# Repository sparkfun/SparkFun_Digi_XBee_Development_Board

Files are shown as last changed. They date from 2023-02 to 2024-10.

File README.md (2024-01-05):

SparkFun Digi XBee® Development Board 
========================================

SparkFun Digi XBee® Development Board (https://www.sparkfun.com/products/21636)

[*SparkFun Digi XBee® Development Board  (21636)*](https://www.sparkfun.com/products/21636)

The SparkFun Digi XBee® Development Board is designed to help you quickly and easily prototype low-power cellular IoT applications using the new Digi XBee 3 Low-Power LTE-M/NB-IoT and Digi XBee RR Pro modules. This board breaks out all the functionality of your XBee module and adds the ability to connect to the cellular network and (drumroll, please) GNSS. 

This is a "kitchen sink" development board that gives you access to the pin functionality of the XBee, includes two USB-C connectors for UART communication and firmware updates, a Qwiic connector for I<sup>2</sup>C capable sensors and peripherals, as well as Reset and D0 buttons and the ability to update firmware on the XBees that have cellular modules. There's also a JST port for a battery to allow your project to be more on the go.

Repository Contents
-------------------

* **/Documentation** - Data sheets, additional product information
* **/Hardware** - Eagle design files (.brd, .sch)
* **/Production** - Production panel files (.brd)

Documentation
--------------
* **[Hookup Guide](https://docs.sparkfun.com/SparkFun_Digi_XBee_Development_Board/)** - Basic hookup guide for the SparkFun Digi XBee® Development Board.

License Information
-------------------

This product is _**open source**_! 

Please review the LICENSE.md file for license information. 

If you have any questions or concerns on licensing, please contact technical support on our [SparkFun forums](https://forum.sparkfun.com/viewforum.php?f=152).

Distributed as-is; no warranty is given.

- Your friends at SparkFun.

_<COLLABORATION CREDIT>_

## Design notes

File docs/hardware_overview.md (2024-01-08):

---
icon: material/cog
---

### Digi XBee® Smart Modem Socket

We've kept the Digi XBee socket consistent with the Digi XBee pinout, so this breakout board is backwards compatible. In order to take full advantage of this board, we recommend one of the newer Digi XBee boards. The [Digi XBee® 3 Low-Power LTE-M/NB-IoT, GNSS, no SIM](https://www.sparkfun.com/products/22329) is a great bet. 

<figure markdown>
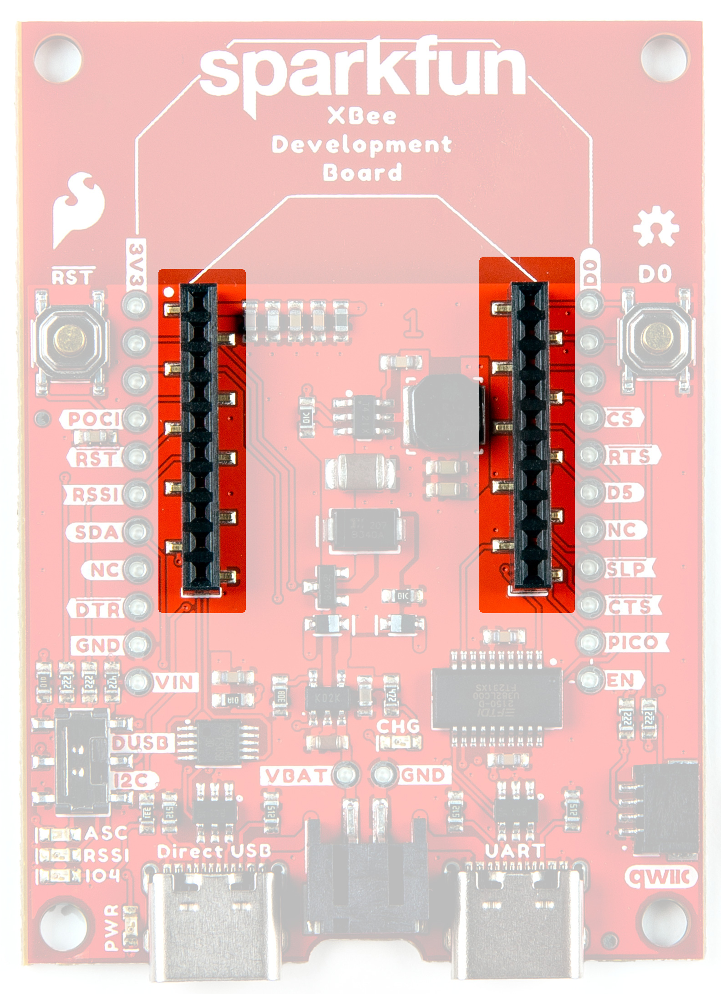
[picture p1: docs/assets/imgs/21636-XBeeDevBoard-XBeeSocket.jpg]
Digi XBee Socket

<figcaption markdown>Digi XBee Socket</figcaption>
</figure>

### Power and USB-C Connectors

There are two USB-C connectors on the board that can provide power. Both can be
plugged in simulatenously. Input VCC range is between <b>3.3V-5.5V</b>. 

<figure markdown>
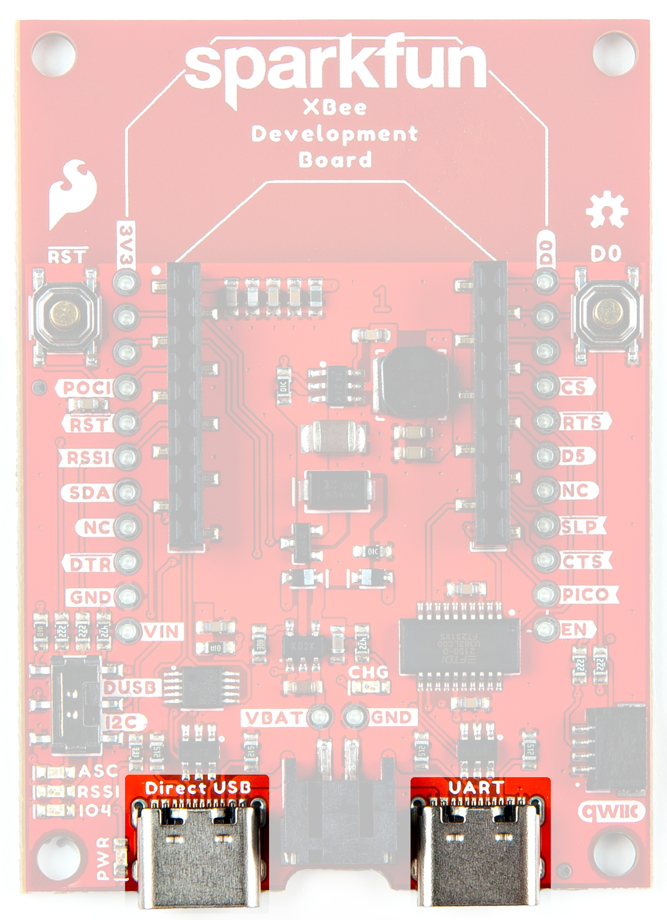
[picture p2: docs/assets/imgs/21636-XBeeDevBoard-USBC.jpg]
USB-C Connectors

<figcaption markdown>USB-C</figcaption>
</figure>

### Direct USB 

Digi XBee 3 modules with cellular capabilities have a u-blox cell module. The firmware for this module can be updated directly from the "Direct USB" USB-C connector. For more information, please refer to the [Digi XBee® 3 Cat1 Smart Modem User Guide](assets/BoardFiles/XBee3_LTE_Cat_1-UserGuide-90002503-1.pdf){ target="_blank" }. 

<figure markdown>
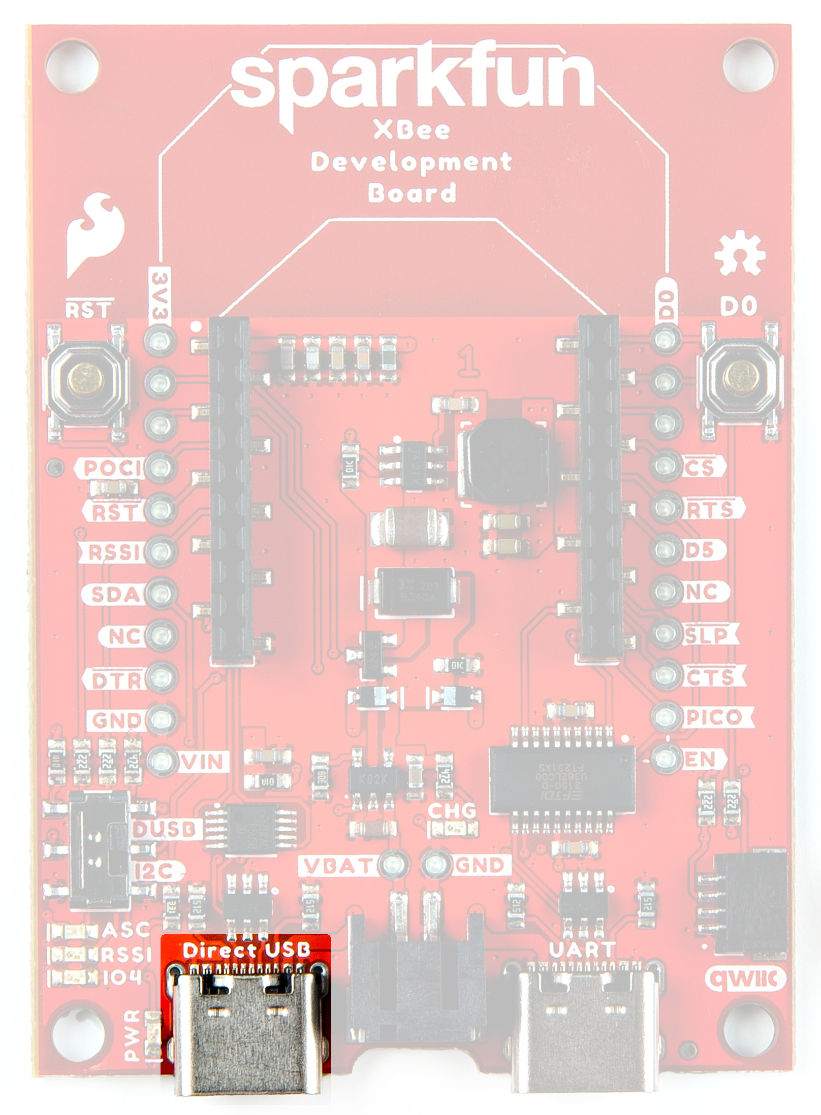
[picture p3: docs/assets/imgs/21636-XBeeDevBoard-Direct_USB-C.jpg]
Direct USB-C

<figcaption markdown>Direct USB-C</figcaption>
</figure>

### Qwiic Connector

The Qwiic connector on the SparkFun Digi XBee® Development Board provides power and I<sup>2</sup>C connectivity to Qwiic breakout boards. Note that I<sup>2</sup>C functionality is not enabled by default. 

<figure markdown>
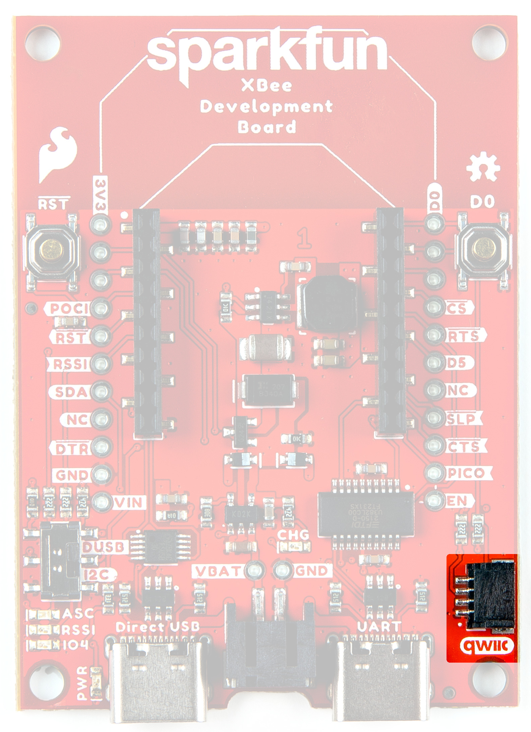
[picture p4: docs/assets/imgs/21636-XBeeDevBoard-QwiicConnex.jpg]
Qwiic Connector

<figcaption markdown>Qwiic Connector</figcaption>
</figure>

### USB Switch

The USB switch allows you to select between Direct USB and I<sup>2</sup>C. Default is Low (I<sup>2</sup>C/SDA).

<figure markdown>
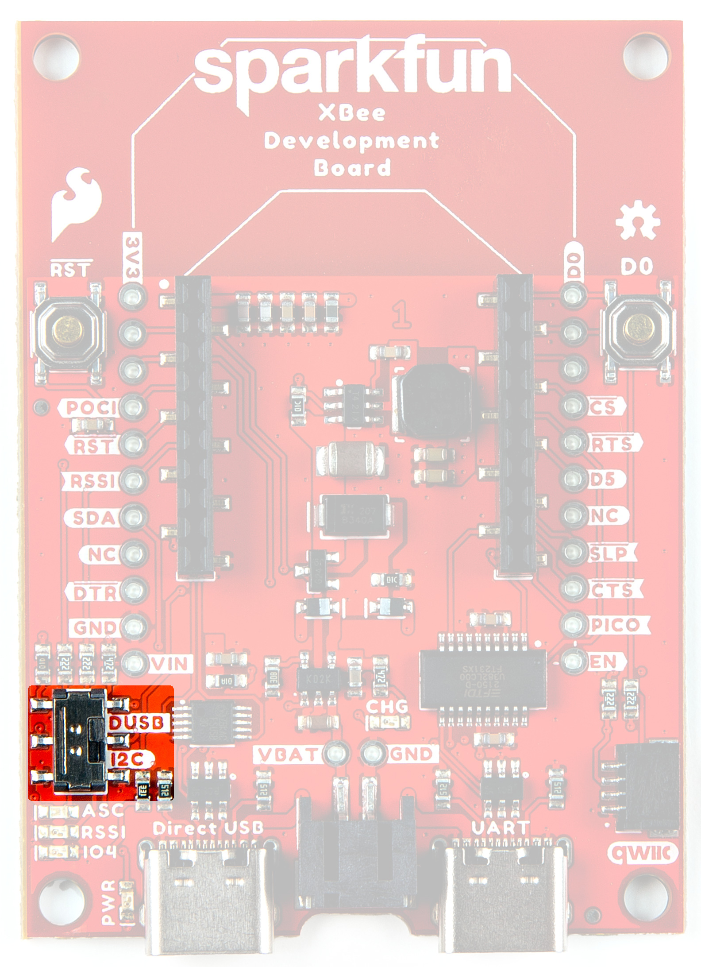
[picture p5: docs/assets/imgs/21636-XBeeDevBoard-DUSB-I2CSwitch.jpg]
DUSB I2C Switch

<figcaption markdown>DUSB I<sup>2</sup>C Switch</figcaption>
</figure>

### Buck Converter - AP63203

The AP63203 is a 2A, synchronous buck converter with a wide input voltage range that fully integrates a 125mΩ high-side power MOSFET and a 68mΩ lowside power MOSFET to provide high-efficiency step-down DC/DC conversion. VIN range is <b>3.8V-5.5V</b>. Output is 2A max. 

<figure markdown>
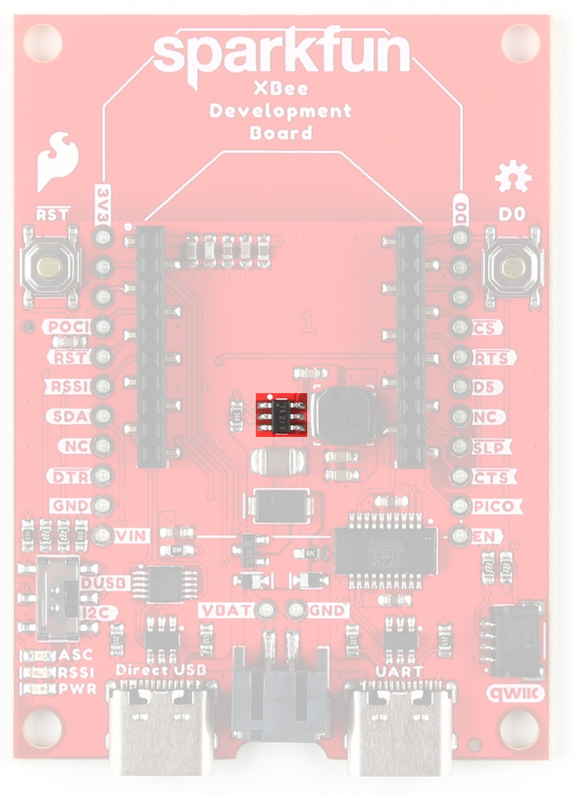
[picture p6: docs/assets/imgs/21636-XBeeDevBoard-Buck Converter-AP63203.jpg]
AP63203 Buck Converter

<figcaption markdown>AP63203 Buck Converter</figcaption>
</figure>

### USB to UART Bridge

The FT231XS translates data between your computer and the Digi XBee. This is one of our favorite chips because it supports all computer platforms and it's easy to work with. If this is the first FTDI chip you've ever connected to your computer (it probably won't be your last), there is some driver installation to get out of the way. We've written a tutorial detailing [How to Install FTDI Drivers tutorial](tutorials/74).

<figure markdown>
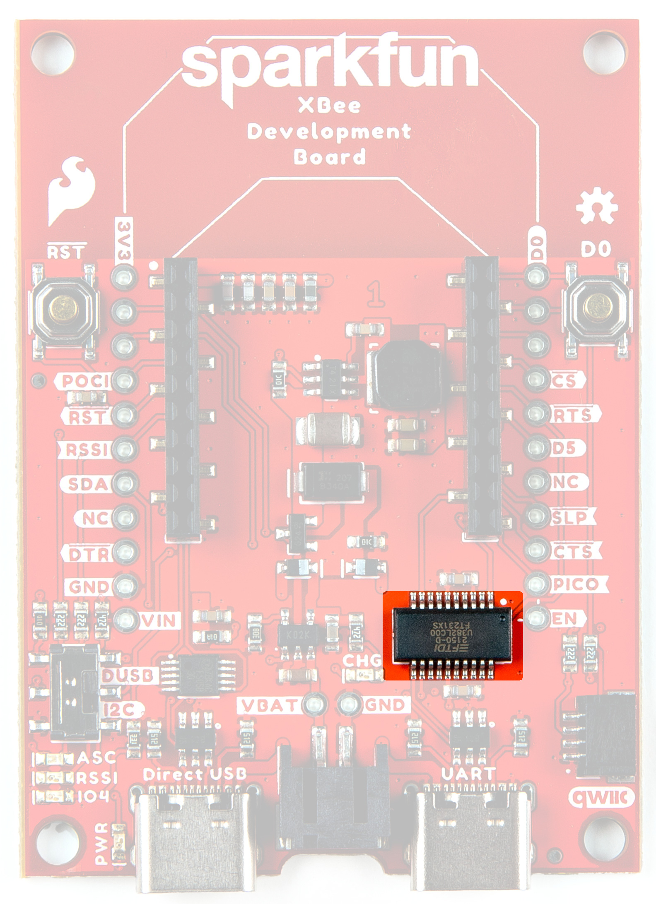
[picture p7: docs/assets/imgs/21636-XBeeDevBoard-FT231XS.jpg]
FT231XS USB to UART Bridge

<figcaption markdown>FT231XS USB to UART Bridge</figcaption>
</figure>

### Lipo Battery Connector

The SparkFun Digi XBee® Development Board includes support for single-cell lithium-polymer (LiPo) batteries, which plug into the board's black 2-pin JST connector. LiPos are perfect for projects on-the-go, or those that just need a little extra oomph. Bonus - you can charge your LiPo battery if the board is also plugged in. 

<figure markdown>
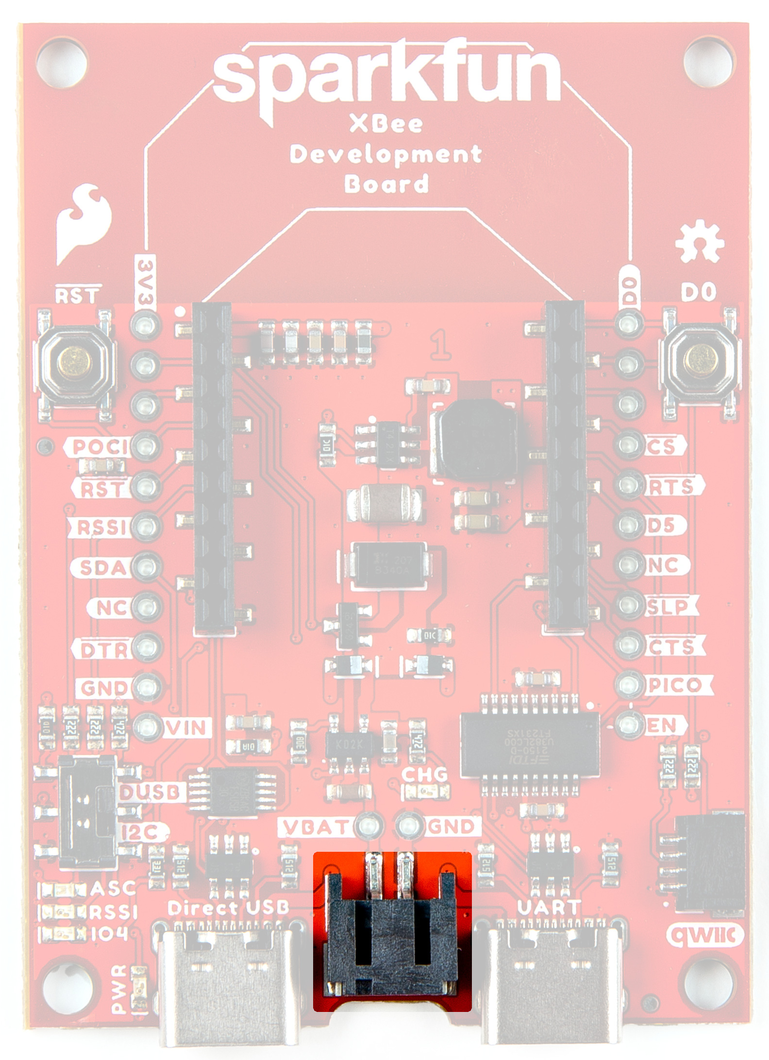
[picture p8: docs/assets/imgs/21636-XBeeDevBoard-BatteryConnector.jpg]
Battery Connector

<figcaption markdown>Battery Connector</figcaption>
</figure>

### GPIO

We've broken out the Digi XBee pins to plated through holes on either side of the board. 

<figure markdown>
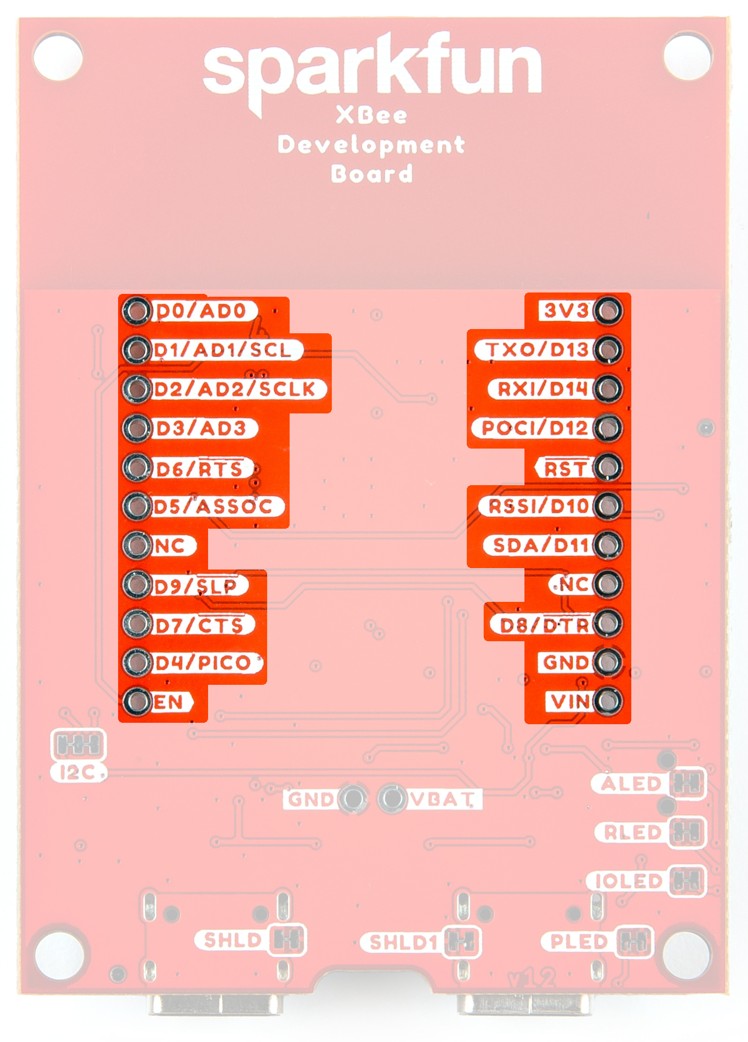
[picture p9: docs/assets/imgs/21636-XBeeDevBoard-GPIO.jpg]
GPIO

<figcaption markdown>GPIO</figcaption>
</figure>

### Buttons 

There are two buttons - D0 and RST. Reset allows you to reset the board without unplugging, the D0 button is provided for user-defined functionality. 

<figure markdown>
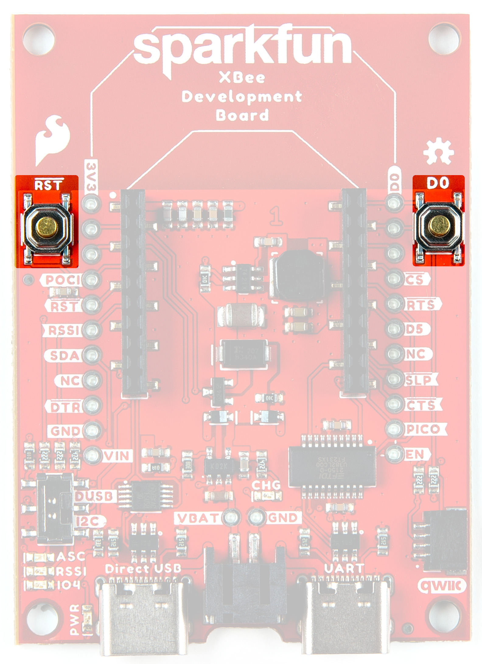
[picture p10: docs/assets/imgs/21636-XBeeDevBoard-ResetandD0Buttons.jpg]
Reset and D0 Buttons

<figcaption markdown>Reset and D0 Buttons</figcaption>
</figure>

### LEDs

There are multiple LED indicator lights on the board: 

<figure markdown>
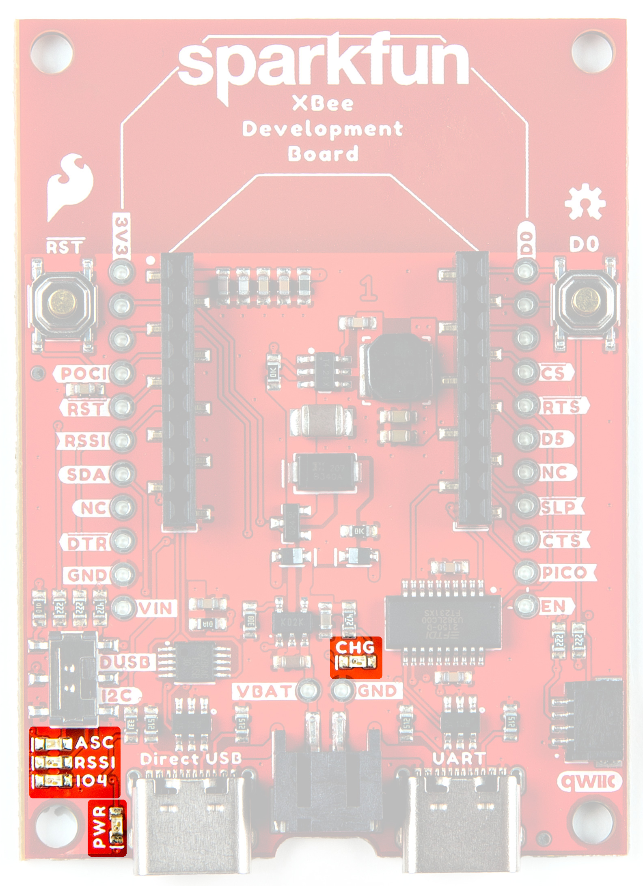
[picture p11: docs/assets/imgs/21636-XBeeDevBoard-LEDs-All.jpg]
LEDs

<figcaption markdown>LEDs</figcaption>
</figure>

#### CHG

This LED lights up when the charge circuit is in use.  

#### PWR

This LED lights up when power is provided to the board. 

#### IO4

This Green LED is a user-defined LED connected to D4 of the XBee. 

#### ASC
This LED on the development board blinks when the Digi XBee is registered to the cellular network.

| Blink | Timing | Meaning |
| --- | --- | --- |
| On | Solid | Not joined to a mobile network |
| Double Blink | ½ second | The last TCP/UDP/SMS attempt failed. If the LED has this pattern, you may need to check DI (Remote Manager Indicator) or CI (Protocol/Connection Indication) for the cause of the error. | 
| Single blink | 1 Second | Normal Operation |

#### RSSI 
This LED is the Received Signal Strength Indicator. When configured, it reflects the received signal strength.

RSSI PWM
The RSSI/PWM output is enabled continuously, unlike other Digi XBee products where the output is enabled for a short period of time after each received transmission. If running on the XBIB development board, DIO10 is connected to the RSSI LEDs, which may be interpreted as follows:

| PWM duty cycle | Number of LEDs turned on | Received signal strength (dBm) |
| --- | --- | --- |
| 79.39% or more | 3 | 83 dBm or higher |
| 62.42% to 79.39% | 2 | -93 to -83 dBm |
| 45.45% to 62.42% | 1 | -103 to -93 dBm |
| Less than 45.45% | 0 | Less than -103 dBm, or no cellular network connection |

### Jumpers

#### SHLD/SHLD1

For most applications, the single point grounding of the Direct USB or UART at the USB-C connector is sufficient. However, should you run into problems with EMI/EMC, we've provided jumpers that allow you to disconnect either connector from ground.

Cut the SHLD jumper for the UART USB-C; cut the SHLD1 jumper for Direct USB. 

<figure markdown>
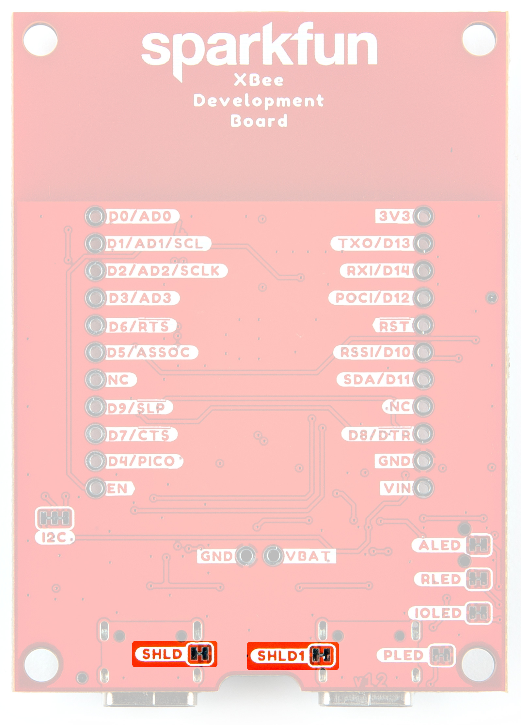
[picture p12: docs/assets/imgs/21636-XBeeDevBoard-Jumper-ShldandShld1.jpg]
Shield Jumpers

<figcaption markdown>Shield Jumpers</figcaption>
</figure>

#### ALED/PLED/RLED/IOLED

If power consumption is an issue (or if you just don't like the LEDs), cut the respective jumper to sever power to the LED. 

* PLED: Red
* ALED: Blue
* RLED (RSSI): Yellow
* IOLED: Green

<figure markdown>
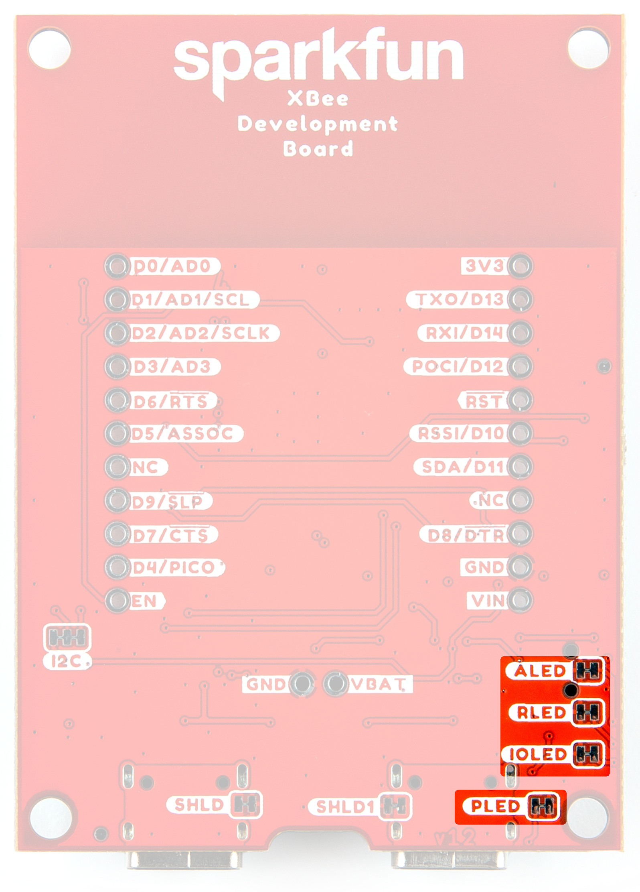
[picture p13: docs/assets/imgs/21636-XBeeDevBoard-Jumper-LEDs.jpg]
LED Jumpers

<figcaption markdown>LED Jumpers</figcaption>
</figure>

#### I2C 

The I<sup>2</sup>C jumper pulls the SDA and SCL pins to VDD (normally 3.3V) through two 2.2K Ohm resistors. If you have multiple Qwiic devices on the same bus you may want to disable these by opening the jumper (assuming they are also operating at 3.3V logic).

<figure markdown>
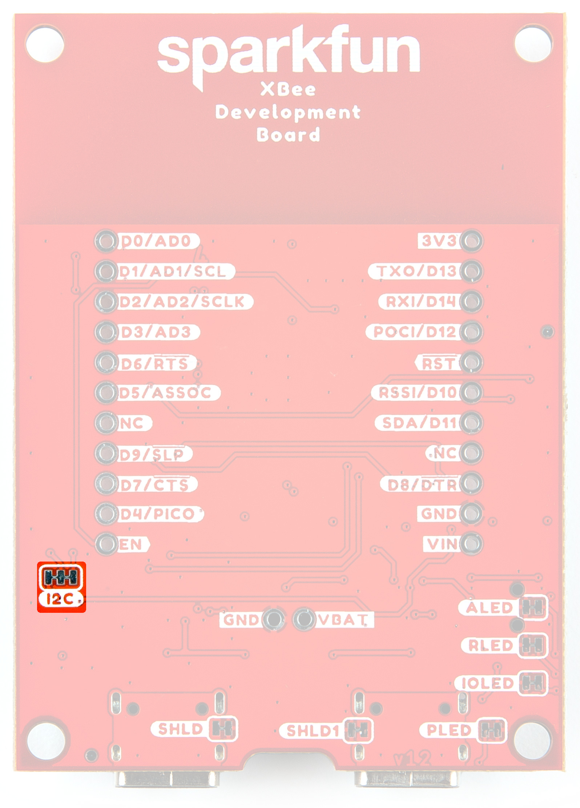
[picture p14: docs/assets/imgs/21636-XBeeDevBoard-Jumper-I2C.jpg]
I2C Jumper

<figcaption markdown>I<sup>2</sup>C Jumper</figcaption>
</figure>

### Board Outline

The overall size of the SparkFun Digi XBee® Development Board is 1.8" by 2.5". For specific measurements, see the image below. 

<figure markdown>
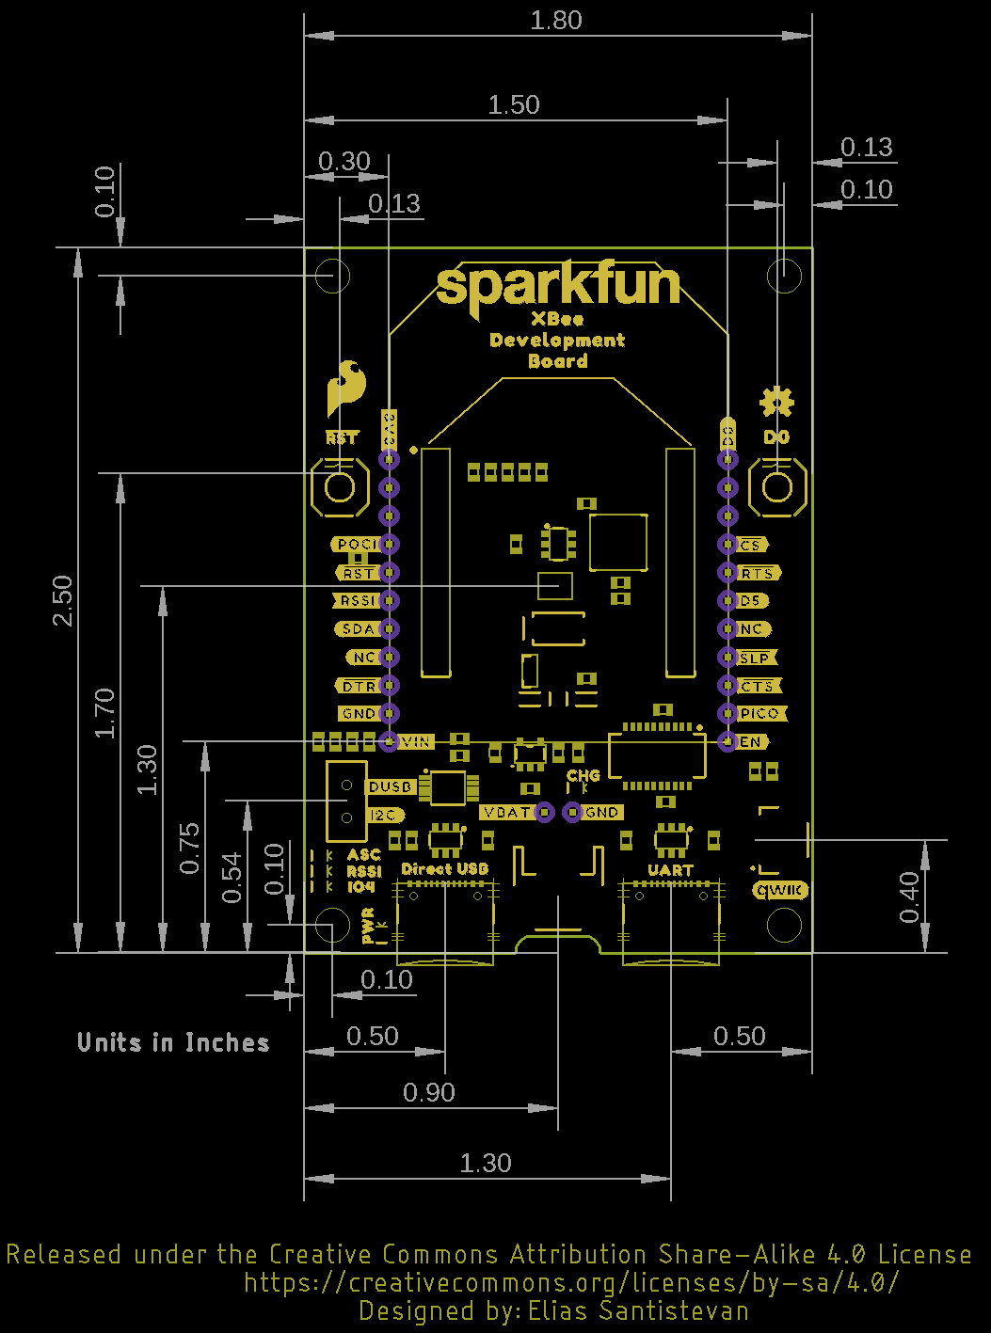
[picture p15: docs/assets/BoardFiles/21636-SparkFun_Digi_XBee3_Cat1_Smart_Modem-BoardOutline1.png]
Board Outline

<figcaption markdown>Board Outline</figcaption>
</figure>

??? tip "Need more measurements?"
	For more information about the board's dimensions, users can download the [Eagle files](assets/BoardFiles/SparkFun_Digi_XBee_Development_Board_EagleFiles.zip) for the board. These files can be opened in Eagle and additional measurements can be made with the dimensions tool.

	??? info ":octicons-download-16:{ .heart } Eagle - Free Download!"
		Eagle is a [CAD]("computer-aided design") program for electronics that is free to use for hobbyists and students. However, it does require an account registration to utilize the software.

		<center>
		[Download from<br>:autodesk-primary:{ .autodesk }](https://www.autodesk.com/products/eagle/free-download "Go to downloads page"){ .md-button .md-button--primary width="250px" }
		</center>
	
	??? info ":straight_ruler: Dimensions Tool"
		This video from Autodesk demonstrates how to utilize the dimensions tool in Eagle, to include additional measurements:

		<center>
		<div class="video">
		<iframe src="https://www.youtube.com/embed/dZLNd1FtNB8" title="EAGLE Dimension Tool" frameborder="0" allow="accelerometer; autoplay; clipboard-write; encrypted-media; gyroscope; picture-in-picture" allowfullscreen></iframe>
		</div>
		</center>

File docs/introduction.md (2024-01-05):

---
icon: material/book-open-page-variant
---

<div class="grid cards desc" markdown>

-    <a href="https://www.sparkfun.com/products/21636">
    **SparkFun Digi XBee® Development Board**<br>
    **SKU:** WRL-21636

    ---

    <figure markdown>
    Product Thumbnail
    </figure></a>
    
-    The SparkFun Digi XBee® Development Board is designed to help you quickly and easily prototype low-power cellular IoT applications using the new Digi XBee 3 Low-Power LTE-M/NB-IoT and Digi XBee RR Pro modules. This board breaks out all the functionality of your XBee module and adds the ability to connect to the cellular network and (drumroll, please) GNSS. This is a "kitchen sink" development board that gives you access to the pin functionality of the XBee, includes two USB-C connectors for UART communication and firmware updates, a Qwiic connector for I<sup>2</sup>C capable sensors and peripherals, as well as Reset and D0 buttons and the ability to update firmware on the XBees that have cellular modules. There's also a JST port for a battery to allow your project to be more on the go.

    <center>
    [Purchase from SparkFun :fontawesome-solid-cart-plus:{ .heart }](https://www.sparkfun.com/products/21636){ .md-button .md-button--primary }
    </center>

</div>

## Required Materials

To follow along with this tutorial, you will need the following materials. You may not need everything though depending on what you have. Add it to your cart, read through the guide, and adjust the cart as necessary.

<div class="grid cards" markdown>

-   <a href="https://www.sparkfun.com/products/21636">
    <figure markdown>
    Product Thumbnail
    </figure>

    ---

    **SparkFun Digi XBee® Development Board**<br>
    WRL-21636</a>

-   <a href="https://www.sparkfun.com/products/22329">
    <figure markdown>
    Product Thumbnail
    </figure>

    ---

    **Digi XBee® 3 Low-Power LTE-M/NB-IoT, GNSS, no SIM**<br>
    WRL-22329</a>

-   <a href="https://www.sparkfun.com/products/14743">
    <figure markdown>
    Product Thumbnail
    </figure>

    ---

    **USB 3.1 Cable A to C - 3 Foot**<br>
    CAB-14743</a>

</div>

## Suggested Reading

As a more professionally oriented product, we will skip over the more fundamental tutorials (i.e. [**Ohm's Law**](https://learn.sparkfun.com/tutorials/voltage-current-resistance-and-ohms-law) and [**What is Electricity?**](https://learn.sparkfun.com/tutorials/what-is-electricity)). However, below are a few tutorials that may help users familiarize themselves with various aspects of the board.

<div class="grid cards hide col-4" markdown align="center">

-   <a href="https://www.sparkfun.com/pages/xbee_guide">
    <figure markdown>
    XBee Buying Guide
    </figure>
    </a>
    <a href="https://www.sparkfun.com/pages/xbee_guide">**XBee Buying Guide**
    </a>

-   <a href="https://learn.sparkfun.com/tutorials/exploring-xbees-and-xctu">
    <figure markdown>
    Exploring XBees and XCTU
    </figure>
    </a>
    <a href="https://learn.sparkfun.com/tutorials/exploring-xbees-and-xctu">**Exploring XBees and XCTU**
    </a>    

-   <a href="https://learn.sparkfun.com/tutorials/serial-communication">
    <figure markdown>
    Serial Communication
    </figure>
    </a>
    <a href="https://learn.sparkfun.com/tutorials/serial-communication">**Serial Communication**
    </a>    

</div>

The SparkFun Digi XBee® Development Board takes advantage of the [Qwiic connect system](https://www.sparkfun.com/qwiic). We recommend familiarizing yourself with the **Logic Levels** and **I<sup>2</sup>C** tutorials. Click on the banner above to learn more about [Qwiic products](https://www.sparkfun.com/qwiic).

<center>
    <iframe width="600" height="327" src="https://www.youtube.com/embed/x0RDEHqFIF8" title="SparkFun's Qwiic Connect System" frameborder="0" allow="accelerometer; autoplay; clipboard-write; encrypted-media; gyroscope; picture-in-picture" allowfullscreen></iframe>
</center>

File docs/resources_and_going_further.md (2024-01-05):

For more information related to the SparkFun Digi XBee® Development Board, check out the resources below:

* [Schematic (PDF)](assets/BoardFiles/SparkFun_Digi_XBee_Development_Board_Schematic.pdf){ target="_blank" }
* [Eagle Files](assets/BoardFiles/SparkFun_Digi_XBee_Development_Board_EagleFiles.zip){ target="_blank" }
* [Board Outline (PNG)](assets/BoardFiles/21636-SparkFun_Digi_XBee3_Cat1_Smart_Modem-BoardOutline1.png){ target="_blank" }
* [GitHub Hardware Repo](https://github.com/sparkfun/SparkFun_Digi_XBee_Development_Board){ target="_blank" }
* [Digi XBee® 3 Cat1 Smart Modem User Guide](assets/BoardFiles/XBee3_LTE_Cat_1-UserGuide-90002503-1.pdf){ target="_blank" }

Or check out other [Digi XBee Projects](https://learn.sparkfun.com/tutorials/tags/xbee) for inspiration:

<table style="border-style:none">
    <tr>
        <td style="vertical-align: text-top;" width="264px">
            <a href="https://www.sparkfun.com/news/3252">
            
            <h3 style="vertical-align: left">Be All That You Can XBee
            </h3></a>
        </td>
        <td style="vertical-align: text-top;" width="264px">
            <div style="text-align: center"><a href="https://www.sparkfun.com/news/2891">
            </div>
            <h3 style="text-align: left">Wireless RC Robot with Arduino and XBees
            </h3></a>
        </td>
        <td style="vertical-align: text-top;" width="264px">
            <div style="text-align: center"><a href="https://www.sparkfun.com/news/2761">
            </div>
            <h3 style="text-align: left">Enginursday: Prototype Capacitive Touch Dance Floor with a Teensy and XBees
            </h3></a>
        </td>
        <td style="vertical-align: text-top;" width="264px">
            <a href="https://www.sparkfun.com/news/2911">
            
            <h3 style="text-align: left">Wireless Gesture-Controlled Robot
            </h3></a>
        </td>
    </tr>
</table>

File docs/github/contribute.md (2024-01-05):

# Contribute: Make an Augmentation!
Spot an improvement opportunity? Feel free to contribute to our open-source design and documentation. 

## :material-file-document-multiple:&nbsp;Improve our Documentation
All of this documentation can be modified by you! Please help us make it better.

* These pages are contained in the [`docs` folder](https://github.com/sparkfun/SparkFun_Digi_XBee_Development_Board/tree/main/docs) of the [SparkFun Digi XBee® Development Board repository](https://github.com/sparkfun/SparkFun_Digi_XBee_Development_Board).

<!-- ### :material-source-pull:&nbsp;Submit a Correction -->
### Submit a Correction

1. With a GitHub account, [fork this repository](https://github.com/sparkfun/SparkFun_Digi_XBee_Development_Board/fork).
2. Add your corrections or improvements to the markdown file.
3. File a pull request with your changes, and enjoy making the ~~words~~ ~~worlds~~ world a better place.
	* Once received, the documentation specialist will automatically be notified.
	* We will review your suggested improvements to make sure they are correct and fit within our documentation standards.

## :material-cog:&nbsp;Improve our Hardware Design
All of our designs are open-source! Please help us make it better.

* Our board design files are contained in the [`Hardware` folder](https://github.com/sparkfun/SparkFun_Digi_XBee_Development_Board/tree/main/Hardware) of the [SparkFun Digi XBee® Development Board repository](https://github.com/sparkfun/SparkFun_Digi_XBee_Development_Board).

<!-- ### :material-source-pull:&nbsp;Submit a Design Enhancement -->
### Submit a Design Enhancement

1. With a GitHub account, [fork this repository](https://github.com/sparkfun/SparkFun_Digi_XBee_Development_Board/fork).
2. Add your design augmentation(s)
3. File a pull request with your changes, and enjoy making the ~~words~~ ~~worlds~~ world a better place.
	1. Once received, the engineer in charge of the original design will automatically be notified.
	2. We will review your suggested improvement(s) to verify that they are within our board design standards and meet our product design requirements.
	3. If approved, we will flag these changes for our next board revision. Congrats! 🍻

		!!! info
			Even if your suggestion is accepted, these changes may not be immediately available for purchase. We may have to cycle through our current product inventory first.

## Contributors&nbsp;:clap:
Let's provide some recognition to the contributors for this project!

GitHub Contributors Image
<br>


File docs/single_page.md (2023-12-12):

---
hide:
  - navigation
  - toc
icon: fontawesome/solid/scroll
---

# Introduction
--8<-- "./docs/introduction.md:5"

# Hardware Overview
--8<-- "./docs/hardware_overview.md:5"

# Hardware Assembly
--8<-- "./docs/hardware_assembly.md:5"

## Software Setup
--8<-- "./docs/software_setup_and_programming.md:5"

# Troubleshooting Tips
--8<-- "./docs/troubleshooting.md:5"

# Resources:
--8<-- "./docs/resources_and_going_further.md:5"

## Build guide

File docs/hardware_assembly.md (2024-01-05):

---
icon: fontawesome/solid/screwdriver-wrench
---

Note the white silkscreen on the Shield PCB - this will help orient your Digi XBee as you're plugging it in. Make sure to match up the Digi XBee's two diagonal edges with the two diagonal lines on the PCB.

<figure markdown>
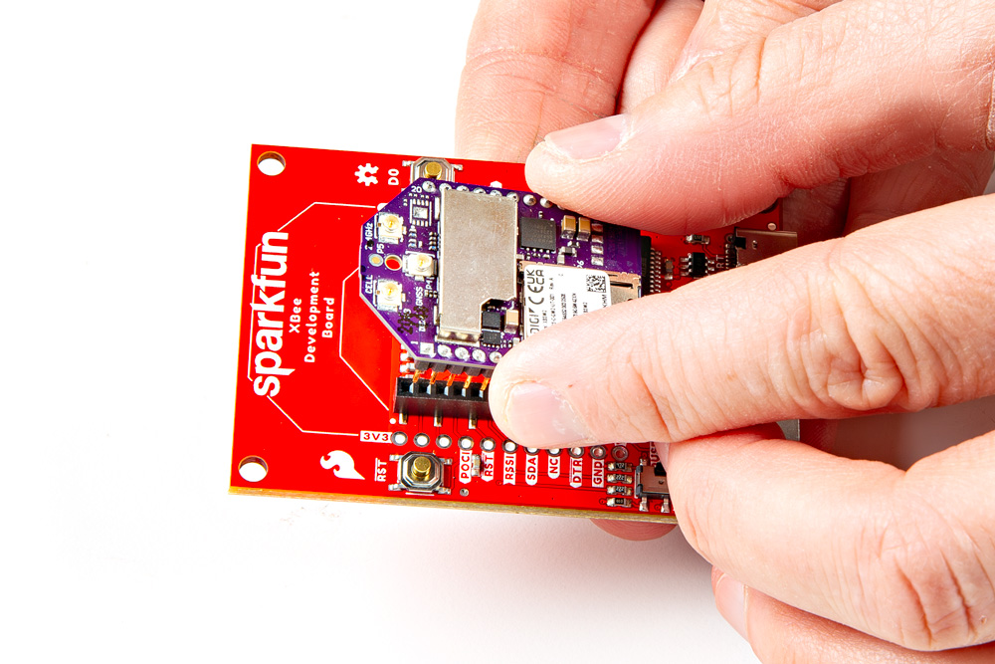
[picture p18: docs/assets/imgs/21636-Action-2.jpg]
Fitting the Digi XBee 3 into the Development Board's Socket

<figcaption markdown>Fitting the Digi XBee 3 into the SparkFun Digi XBee® Development Board's Socket</figcaption>
</figure>

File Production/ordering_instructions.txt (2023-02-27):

panel size, 106x216mm
PCB thickness, 1.6mm
number of layers, 4
soldermask color, Red
silkscreen color, White
oz copper, 1oz
finish, HASL lead free
stencils, top
pcs per panel, 6
min trace width, 0.2032mm / 0.0080in
min drill size, 0.3048mm / 0.0120in
filename to layer stackup 1/2/3/4: GTL, GL2, GL3, GBL

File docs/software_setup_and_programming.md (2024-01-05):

We have a number of tutorials detailing how to work with Digi XBees and their associated software. In particular, [XCTU](https://www.digi.com/products/embedded-systems/digi-xbee/digi-xbee-tools/xctu) is free software provided by Digi (the manufacturer of XBee), that provides a quick and easy way to configure and manage Digi XBees as well as test XBee networks. 

If you haven't worked with XCTU before, head on over to our [Exploring XBees and XCTU tutorial](https://learn.sparkfun.com/tutorials/exploring-xbees-and-xctu/all#starting-with-x-ctu) to get set up.  

<center><table class="tg">
  <tr>
    <th class="tg-v0mg"><a href="https://learn.sparkfun.com/tutorials/exploring-xbees-and-xctu/all#starting-with-x-ctu">Exploring XBees and XCTU tutorial</a></th>
  </tr>
  <tr>
    <td class="tg-v0mg"><i>Exploring XBees and XCTU tutorial</i></td>
  </tr>
</table>
</center>

You might also check out this [XBee WiFi Hookup Guide](https://learn.sparkfun.com/tutorials/xbee-wifi-hookup-guide) if your project includes WiFi! 

<center>
<table class="tg">
  <tr>
    <th class="tg-v0mg"><a href="https://learn.sparkfun.com/tutorials/xbee-wifi-hookup-guide">XBee WiFi Hookup Guide</a></th>
  </tr>
  <tr>
    <td class="tg-v0mg"><i>XBee WiFi Hookup Guide</i></td>
  </tr>
</table>
</center>

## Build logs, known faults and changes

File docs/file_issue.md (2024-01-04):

# Did we make a mistake?

Spot something wrong? Please let us know. 

!!! attention
    This is not where customers should seek assistance on a product. If you require technical assistance or have questions about a product that is not working as expected, please head over to the [SparkFun Technical Assistance](https://www.sparkfun.com/technical_assistance) page for some initial troubleshooting.
    <center>
    [SparkFun Technical Assistance Page](https://www.sparkfun.com/technical_assistance){ .md-button .md-button--primary }
    </center>
    
    If you can't find what you need there, you'll need a [Forum Account](https://forum.sparkfun.com/ucp.php?mode=register) to search product forums and post questions.

## Discrepancies in the Documentation

All of this documentation can be modified by you! Please help us make it better.

* The documentation files for these pages are contained in the [`docs` folder](https://github.com/sparkfun/SparkFun_XBee_Development_Board/tree/main/docs) of the [SparkFun Digi XBee® Development Board](https://github.com/sparkfun/SparkFun_XBee_Development_Board) repository.

### Spot something wrong?
If a section of the documentation is incorrect, please [open an issue](https://github.com/sparkfun/SparkFun_XBee_Development_Board/issues) and let us know.

### Do you have a suggested correction?
1. With a GitHub account, fork this repo
2. Add your correction(s) or improvement(s) to the markdown file(s)
3. File a pull request with your changes, and enjoy making the ~~words~~ ~~worlds~~ world a better place.
    * Once received, the documentation specialist will automatically be notified.
    * We will review your suggested improvement(s) to make sure they are correct and fit within our documentation standards.

## Problems in the Hardware Design

All of our designs are open-source! Please help us make it better.

* Our board design files are contained in the [`Hardware` folder](https://github.com/sparkfun/SparkFun_XBee_Development_Board/tree/main/Hardware) of the [SparkFun Digi XBee® Development Board](https://github.com/sparkfun/SparkFun_XBee_Development_Board) repository. 

### Does something not make sense?
If part of the design is confusing, please [open an issue](https://github.com/sparkfun/SparkFun_XBee_Development_Board/issues) and let us know.

### Did we forget to include an important function of the board?
* Please keep in mind that we may intentionally exclude certain functions of the board to meet our product design requirements. *(For example, our Qwiic Micro boards are intended to fit on a small board layout and only use I<sup>2</sup>C communication; therefore, we may not have the SPI and interrupt pins available for users.)*
* If part of the board's functionality is missing, please [open an issue](https://github.com/sparkfun/SparkFun_XBee_Development_Board/issues) and file a feature request.

### Do you wish to contribute directly to improving the board design?
1. With a GitHub account, Fork this repo
2. Add your design improvement(s)
3. File a pull request with your changes, and enjoy making the ~~words~~ ~~worlds~~ world a better place.
    * Once received, the engineer in charge of the original design will automatically be notified.
    * We will review your suggested improvement(s), if they are within our board design standards and meet our product design requirements, we will flag these changes for our next board revision. *(Please note, that even if your suggestion is accepted, these changes may not be immediate. We may have to cycle through our current product inventory first.)*

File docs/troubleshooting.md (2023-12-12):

---
icon: fontawesome/solid/question
---

!!! note
    <span class="glyphicon glyphicon-question-sign" aria-hidden="true"></span>
        <strong> Not working as expected and need help? </strong> <br /><br />

    If you need technical assistance and more information on a product that is not working as you expected, we recommend heading on over to the <a href="https://www.sparkfun.com/technical_assistance">SparkFun Technical Assistance</a> page for some initial troubleshooting. <br /><br />

    <div style="text-align: center"><a href="https://www.sparkfun.com/technical_assistance" target="sfe_technical_assistance" class="md-button">SparkFun Technical Assistance Page</a></div>

    If you don't find what you need there, the <a href="https://forum.sparkfun.com/index.php">SparkFun Forums</a> are a great place to find and ask for help. If this is your first visit, you'll need to <a href="https://forum.sparkfun.com/ucp.php?mode=register">create a Forum Account</a> to search product forums and post questions.<br /><br />

    <div style="text-align: center"><a href="https://forum.sparkfun.com/ucp.php?mode=register" class="md-button">Create New Forum Account</a>&nbsp;&nbsp;&nbsp;<a href="https://forum.sparkfun.com/index.php" class="md-button md-button--primary">Log Into SparkFun Forums</a></div>

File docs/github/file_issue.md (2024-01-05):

# Did we make a mistake?

Spot something wrong? Please let us know. 

<!-- Technical Assistance Box -->
!!! warning "Need Help?"
    If you need technical assistance or more information on a product that is not working as you expected, we recommend heading on over to the [SparkFun Technical Assistance](https://www.sparkfun.com/technical_assistanc) page for some initial troubleshooting. This **Submit Issues** page is not where users should seek assistance.

    <center>
    [SparkFun Technical Assistance Page](https://www.sparkfun.com/technical_assistance){ .md-button .md-button--primary }
    </center>
    
    If you can't find what you need there, the [SparkFun Forums](https://forum.sparkfun.com/index.php) is a great place to search the product forums and ask questions.
    
    !!! info "Account Registration Required"
        For your first visit to our forum, you'll need to create a [Forum Account](https://forum.sparkfun.com/ucp.php?mode=register) to post questions.

## Discrepancies in the Documentation

All of our documentation can be modified by you! Please help us make it better.

* The documentation files for these pages are contained in the [`docs` folder](https://github.com/sparkfun/SparkFun_Digi_XBee_Development_Board/tree/main/docs) of the [SparkFun Digi XBee® Development Board repository](https://github.com/sparkfun/SparkFun_Digi_XBee_Development_Board).

### 🔍 Spot something wrong?

If a section of the documentation is incorrect, please [open an issue](https://github.com/sparkfun/SparkFun_Digi_XBee_Development_Board/issues) and let us know.

### Do you have a suggested correction?

1. With a GitHub account, [fork this repository](https://github.com/sparkfun/SparkFun_Digi_XBee_Development_Board/fork).
2. Add your correction(s) or improvement(s) to the markdown file(s)
3. File a pull request with your changes, and enjoy making the ~~words~~ ~~worlds~~ world a better place.
	* Once received, the documentation specialist will automatically be notified.
	* We will review your suggested improvement(s) to make sure they are correct and fit within our documentation standards.

## Problems in the Hardware Design

All of our designs are open-source! Please help us make it better.

* Our board design files are contained in the [`Hardware` folder](https://github.com/sparkfun/SparkFun_Digi_XBee_Development_Board/tree/main/Hardware) of the [SparkFun Digi XBee® Development Board repository](https://github.com/sparkfun/SparkFun_Digi_XBee_Development_Board).

### Does something not make sense? 🤔

If part of the design is confusing, please [open an issue](https://github.com/sparkfun/SparkFun_Digi_XBee_Development_Board/issues) and let us know.

### Did we forget to include an important function of the board? 🤦

If part of the board's functionality is missing, please [open an issue](https://github.com/sparkfun/SparkFun_Digi_XBee_Development_Board/issues) and file a feature request.

!!! tip "Design Considerations"
	Please keep in mind that we may intentionally exclude certain functions of the board to meet our product design requirements.
	
	* *For example, our Qwiic Micro boards are intended to fit on a small board layout and only use I<sup>2</sup>C communication; therefore, we may not have the SPI and interrupt pins available for users.*

### Do you wish to contribute directly to improving the board design?

1. With a GitHub account, [fork this repository](https://github.com/sparkfun/SparkFun_Digi_XBee_Development_Board/fork).
2. Add your design augmentation(s)
3. File a pull request with your changes, and enjoy making the ~~words~~ ~~worlds~~ world a better place.
	1. Once received, the engineer in charge of the original design will automatically be notified.
	2. We will review your suggested improvement(s) to verify that they are within our board design standards and meet our product design requirements.
	3. If approved, we will flag these changes for our next board revision. Congrats! 🍻

		!!! info
			Even if your suggestion is accepted, these changes may not be immediately available for purchase. We may have to cycle through our current product inventory first.

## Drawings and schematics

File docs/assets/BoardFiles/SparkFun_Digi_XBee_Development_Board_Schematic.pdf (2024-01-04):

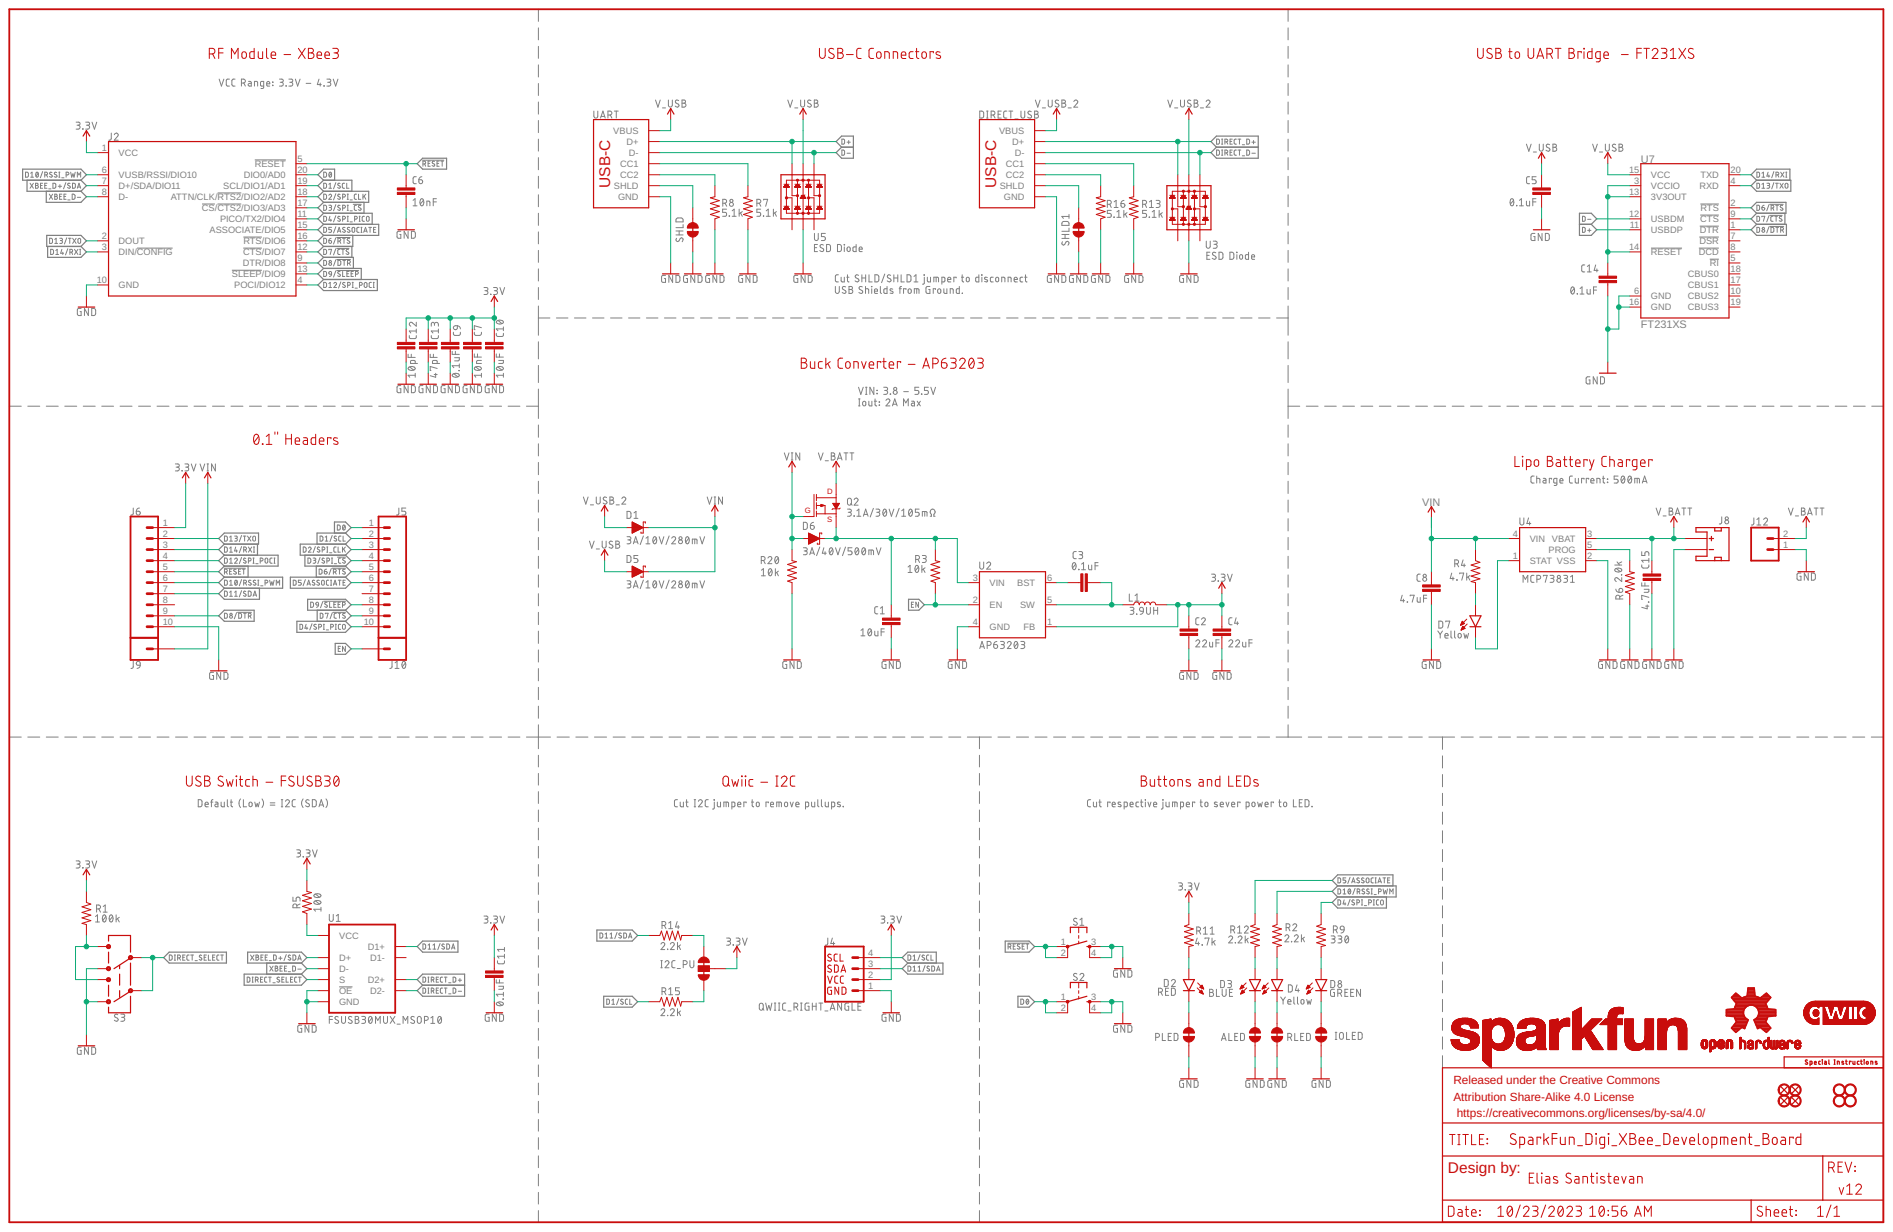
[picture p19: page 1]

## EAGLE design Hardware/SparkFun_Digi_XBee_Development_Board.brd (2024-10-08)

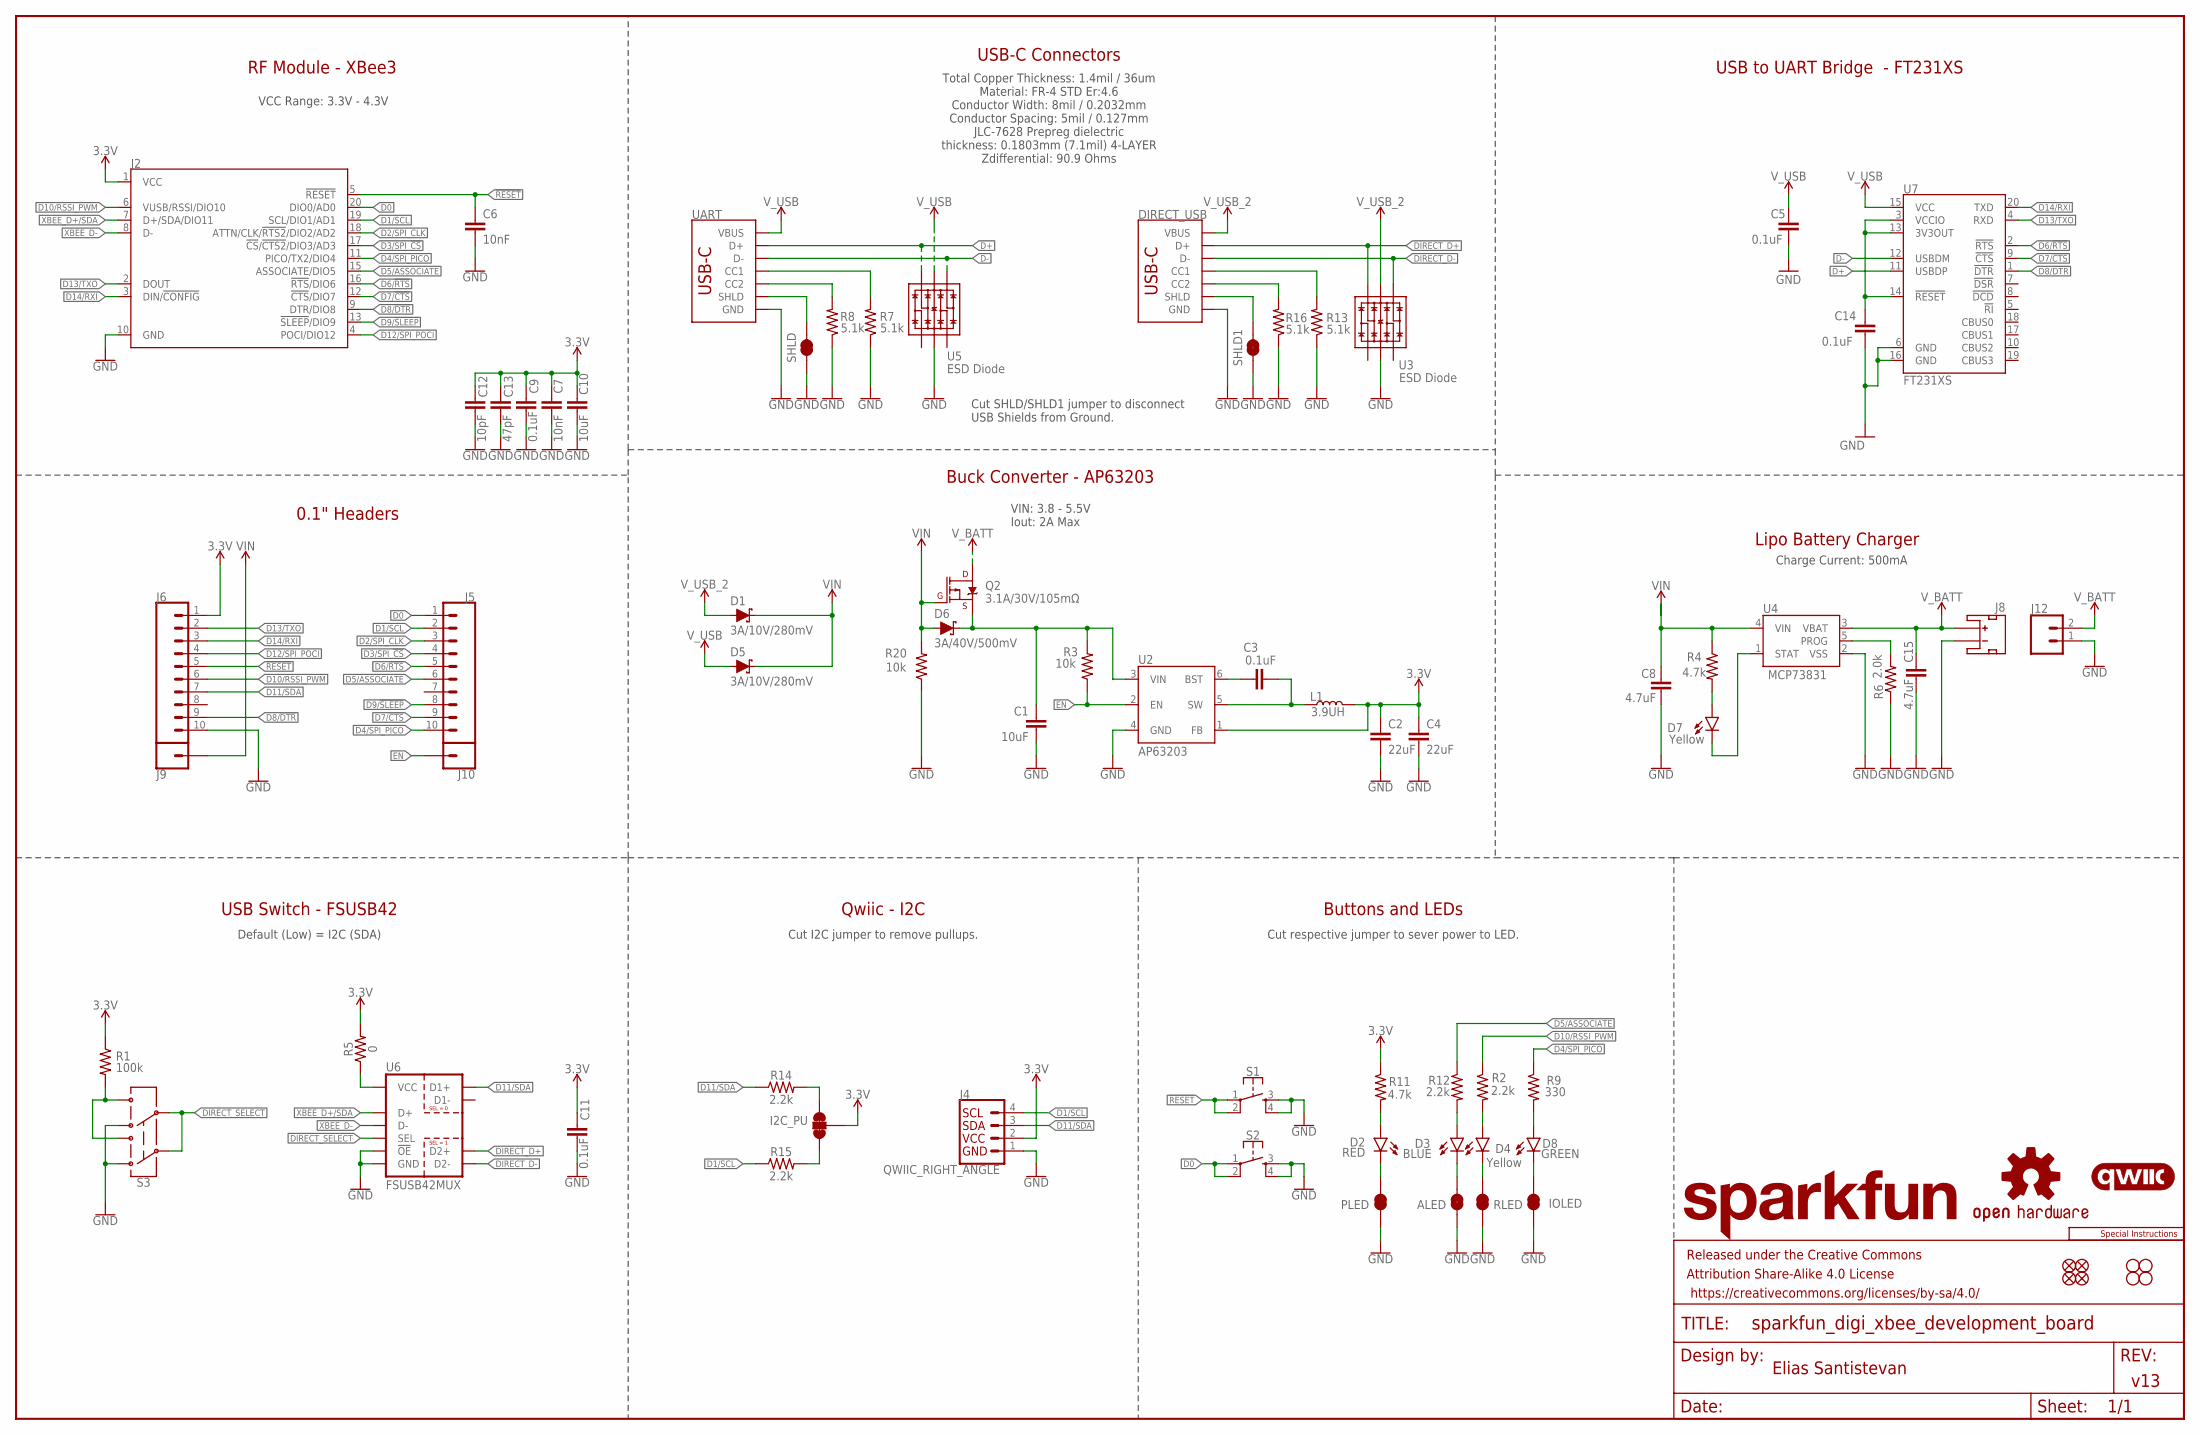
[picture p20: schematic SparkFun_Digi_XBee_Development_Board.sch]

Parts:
ALED: JUMPER-SMT_2_NC_TRACE_SILK; SMT-JUMPER_2_NC_TRACE_SILK
C1: 10uF; 1210
C2, C4: 22uF; 0603
C3, C5, C9, C11, C14: 0.1uF; 0603
C6, C7: 10nF; 0603
C8, C15: 4.7uF; 0603
C10: 10uF; 0603
C12: 10pF; 0603
C13: 47pF; 0603
D1, D5: 3A/10V/280mV; SOD-323
D2: RED; LED-0603
D3: BLUE; LED-0603
D4, D7: Yellow; LED-0603
D6: 3A/40V/500mV; SMA-DIODE
D8: GREEN; LED-0603
DIRECT_USB: USB Female Type C Connector; USB-C-16P-4LAYER-ISOLATED
FD1, FD2, FD3, FD4: FIDUCIAL1X2; FIDUCIAL-1X2
FRAME1: FRAME-LEDGER; CREATIVE_COMMONS
H1, H2, H3, H4: STAND-OFFTIGHT; STAND-OFF-TIGHT
I2C_PU: JUMPER-SMT_3_2-NC_TRACE_SILK; SMT-JUMPER_3_2-NC_TRACE_SILK
IOLED: JUMPER-SMT_2_NC_TRACE_SILK; SMT-JUMPER_2_NC_TRACE_SILK
J2: XBEE_UPDATEXBEE_SMD; XBEE3-SMD
J4: QWIIC_RIGHT_ANGLE; JST04_1MM_RA
J5, J6: CONN_10NO_SILK_PTH_FEMALE; 1X10_NO_SILK
J8: JST_2MM_MALE; JST-2-SMD
J9, J10: CONN_01PTH_NO_SILK_STAND; 1X01_NO_SILK_STAND
J12: CONN_021X02_NO_SILK; 1X02_NO_SILK
L1: 3.9UH; INDUCTOR_3.9UH
LOGO1: SFE_LOGO_NAME.2_INCH; SFE_LOGO_NAME_.2
LOGO2: OSHW-LOGOS; OSHW-LOGO-S
LOGO3: QWIIC_LOGO_5MM; QWIIC_5MM
LOGO5: SPECIAL_INSTRUCTIONS-ORDERING; ORDERING_INSTRUCTIONS
PLED: JUMPER-SMT_2_NC_TRACE_SILK; SMT-JUMPER_2_NC_TRACE_SILK
Q2: 3.1A/30V/105mΩ; SOT23-3
R1: 100k; 0603
R2, R12, R14, R15: 2.2k; 0603
R3, R20: 10k; 0603
R4, R11: 4.7k; 0603
R5: 0; 0603
R6: 2.0k; 0603
R7, R8, R13, R16: 5.1k; 0603
R9: 330; 0603
RLED: JUMPER-SMT_2_NC_TRACE_SILK; SMT-JUMPER_2_NC_TRACE_SILK
S1, S2: MOMENTARY-SWITCH-SPST-2-SMD-5.2MM-TALL; TACTILE_SWITCH_SMD_5.2MM
S3: SWITCH-DPDT-SMD-AYZ0202; SWITCH_DPDT_SMD_AYZ0202
SHLD, SHLD1: JUMPER-SMT_2_NC_TRACE_SILK; SMT-JUMPER_2_NC_TRACE_SILK
U2: AP63203; SOT23-6
U3, U5: ESD Diode; SOT-23-6
U4: MCP73831; SOT23-5
U6: FSUSB42MUX; MSOP10
U7: FT231XS; SSOP20_L
UART: USB Female Type C Connector; USB-C-16P-4LAYER-ISOLATED

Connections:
3.3V: C2.1, C4.1, C7.1, C9.1, C10.1, C11.1, C12.1, C13.1, I2C_PU.2, J2.1 (VCC), J4.2, J6.1, L1.P$2 (2), R1.1, R5.2, R11.1, U2.1 (FB)
!RESET!: C6.1, J2.5 (!RESET!), J6.5, S1.1, S1.2
ALED: ALED.2, D3.C
D0: J2.20 (DIO0/AD0), J5.1, S2.1, S2.2
D1/SCL: J2.19 (SCL/DIO1/AD1), J4.4, J5.2, R15.1
D2/SPI_CLK: J2.18 (ATTN/CLK/!RTS2!/DIO2/AD2), J5.3
D3/SPI_!CS!: J2.17 (!CS!/!CTS2!/DIO3/AD3), J5.4
D4/SPI_PICO: J2.11 (PICO/TX2/DIO4), J5.10, R9.1
D5/ASSOCIATE: J2.15 (ASSOCIATE/DIO5), J5.6, R12.1
D6/!RTS!: J2.16 (!RTS!/DIO6), J5.5, U7.2 (!RTS)
D7/!CTS!: J2.12 (!CTS!/DIO7), J5.9, U7.9 (!CTS)
D8/!DTR!: J2.9 (DTR/DIO8), J6.9, U7.1 (!DTR)
D9/!SLEEP!: J2.13 (!SLEEP!/DIO9), J5.8
D10/RSSI_PWM: J2.6 (VUSB/RSSI/DIO10), J6.6, R2.1
D11/SDA: J4.3, J6.7, R14.1, U6.7 (D1+)
D12/SPI_POCI: J2.4 (POCI/DIO12), J6.4
D13/TXO: J2.2 (DOUT), J6.2, U7.4 (RXD)
D14/RXI: J2.3 (DIN/!CONFIG!), J6.3, U7.20 (TXD)
D+: U5.6 (IO4), U7.11 (USBDP), UART.A6 (D+), UART.B6 (D+)
D-: U5.4 (IO3), U7.12 (USBDM), UART.A7 (D-), UART.B7 (D-)
DIRECT_D+: DIRECT_USB.A6 (D+), DIRECT_USB.B6 (D+), U3.6 (IO4), U6.9 (D2+)
DIRECT_D-: DIRECT_USB.A7 (D-), DIRECT_USB.B7 (D-), U3.4 (IO3), U6.8 (D2-)
DIRECT_SELECT: S3.2, S3.5, U6.2 (SEL)
EN: J10.1, R3.1, U2.2 (EN)
FIRMWARE: R1.2, S3.1, S3.4
GND: ALED.1, C1.2, C2.2, C4.2, C5.2, C6.2, C7.2, C8.2, C9.2, C10.2, C11.2, C12.2, C13.2, C14.2, C15.2, DIRECT_USB.GND, DIRECT_USB.GND2 (GND), IOLED.1, J2.10 (GND), J4.1, J6.10, J8.1 (-), J12.1, PLED.1, R6.1, R7.1, R8.1, R13.1, R16.1, R20.1, RLED.1, S1.3, S1.4, S2.3, S2.4, S3.3, S3.6, SHLD.1, SHLD1.1, U2.4 (GND), U3.2 (VSS), U4.2 (VSS), U5.2 (VSS), U6.5 (GND), U6.10 (!OE!), U7.6 (GND), U7.16 (GND), UART.GND, UART.GND2 (GND)
IOLED: D8.C, IOLED.2
unnamed: C3.1, U2.6 (BST)
unnamed: D4.A, R2.2
unnamed: R5.1, U6.1 (VCC)
unnamed: R8.2, UART.B5 (CC2)
unnamed: R7.2, UART.A5 (CC1)
unnamed: R6.2, U4.5 (PROG)
unnamed: D2.A, R11.2
unnamed: C3.2, L1.P$1 (1), U2.5 (SW)
unnamed: D7.C, U4.1 (STAT)
unnamed: D7.A, R4.2
unnamed: I2C_PU.3, R14.2
unnamed: D3.A, R12.2
unnamed: I2C_PU.1, R15.2
unnamed: DIRECT_USB.B5 (CC2), R16.2
unnamed: C1.1, D6.C, Q2.2 (S), R3.2, U2.3 (VIN)
unnamed: DIRECT_USB.A5 (CC1), R13.2
unnamed: D8.A, R9.2
unnamed: C14.1, U7.3 (VCCIO), U7.13 (3V3OUT), U7.14 (!RESET)
PLED: D2.C, PLED.2
RLED: D4.C, RLED.2
SHLD: SHLD.2, UART.SHLD1 (SHLD), UART.SHLD2 (SHLD), UART.SHLD3 (SHLD), UART.SHLD4 (SHLD), UART.SHLD5 (SHLD), UART.SHLD6 (SHLD), UART.SHLD7 (SHLD), UART.SHLD8 (SHLD)
SHLD1: DIRECT_USB.SHLD1 (SHLD), DIRECT_USB.SHLD2 (SHLD), DIRECT_USB.SHLD3 (SHLD), DIRECT_USB.SHLD4 (SHLD), DIRECT_USB.SHLD5 (SHLD), DIRECT_USB.SHLD6 (SHLD), DIRECT_USB.SHLD7 (SHLD), DIRECT_USB.SHLD8 (SHLD), SHLD1.2
VIN: C8.1, D1.C, D5.C, D6.A, J9.1, Q2.1 (G), R4.1, R20.2, U4.4 (VIN)
V_BATT: C15.1, J8.2 (+), J12.2, Q2.3 (D), U4.3 (VBAT)
V_USB: C5.1, D5.A, U5.5 (VCC), U7.15 (VCC), UART.VBUS1 (VBUS), UART.VBUS2 (VBUS)
V_USB_2: D1.A, DIRECT_USB.VBUS1 (VBUS), DIRECT_USB.VBUS2 (VBUS), U3.5 (VCC)
XBEE_D+/SDA: J2.7 (D+/SDA/DIO11), U6.3 (D+)
XBEE_D-: J2.8 (D-), U6.4 (D-)

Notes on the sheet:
VCC Range: 3.3V - 4.3V
USB to UART Bridge - FT231XS
Buck Converter - AP63203
Lipo Battery Charger
Cut SHLD/SHLD1 jumper to disconnect USB Shields from Ground.
Qwiic - I2C
v13
Elias Santistevan
USB Switch - FSUSB42
Default (Low) = I2C (SDA)
Buttons and LEDs
VIN: 3.8 - 5.5V Iout: 2A Max
USB-C Connectors
Cut I2C jumper to remove pullups.
Cut respective jumper to sever power to LED.
RF Module - XBee3
0.1" Headers
Charge Current: 500mA
Total Copper Thickness: 1.4mil / 36um Material: FR-4 STD Er:4.6 Conductor Width: 8mil / 0.2032mm Conductor Spacing: 5mil / 0.127mm JLC-7628 Prepreg dielectric thickness: 0.1803mm (7.1mil) 4-LAYER Zdifferential: 90.9 Ohms

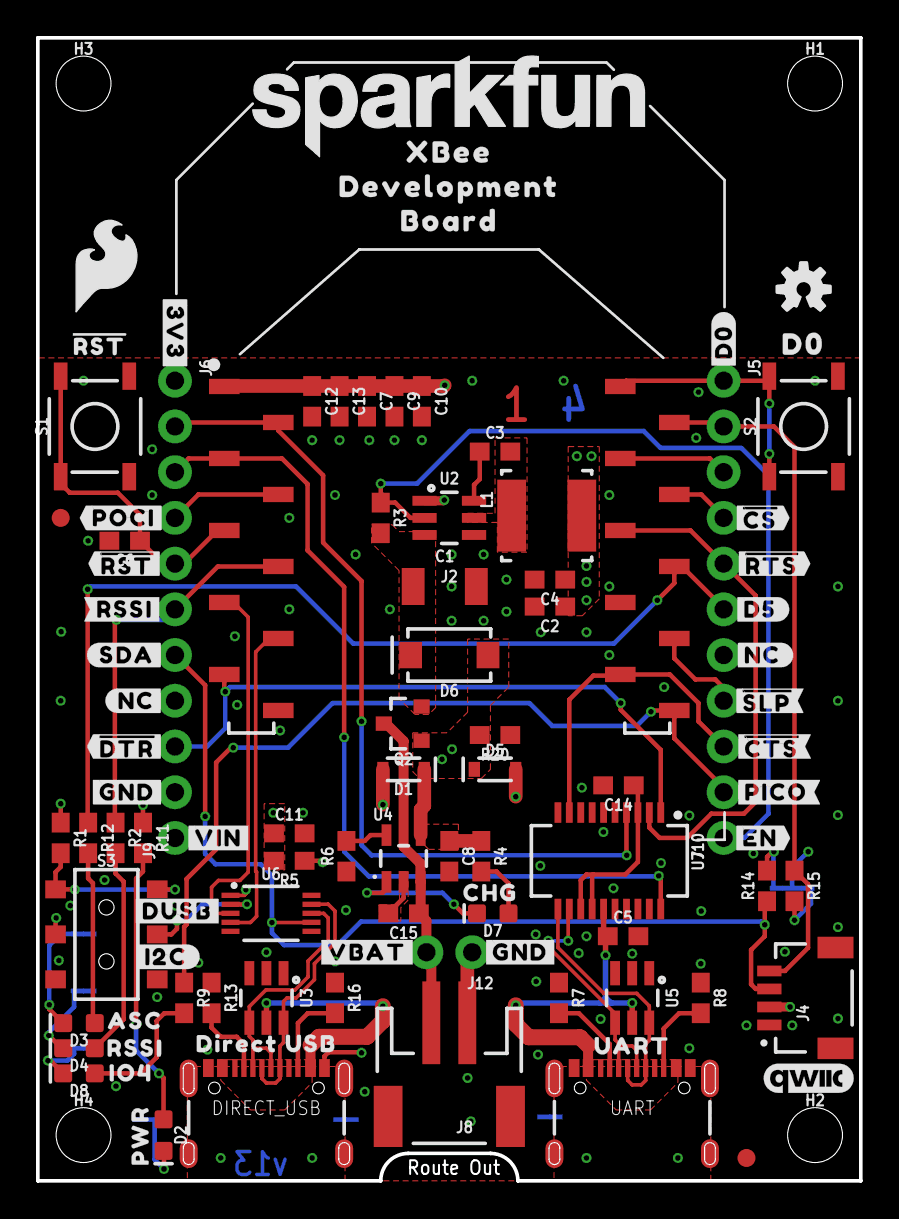
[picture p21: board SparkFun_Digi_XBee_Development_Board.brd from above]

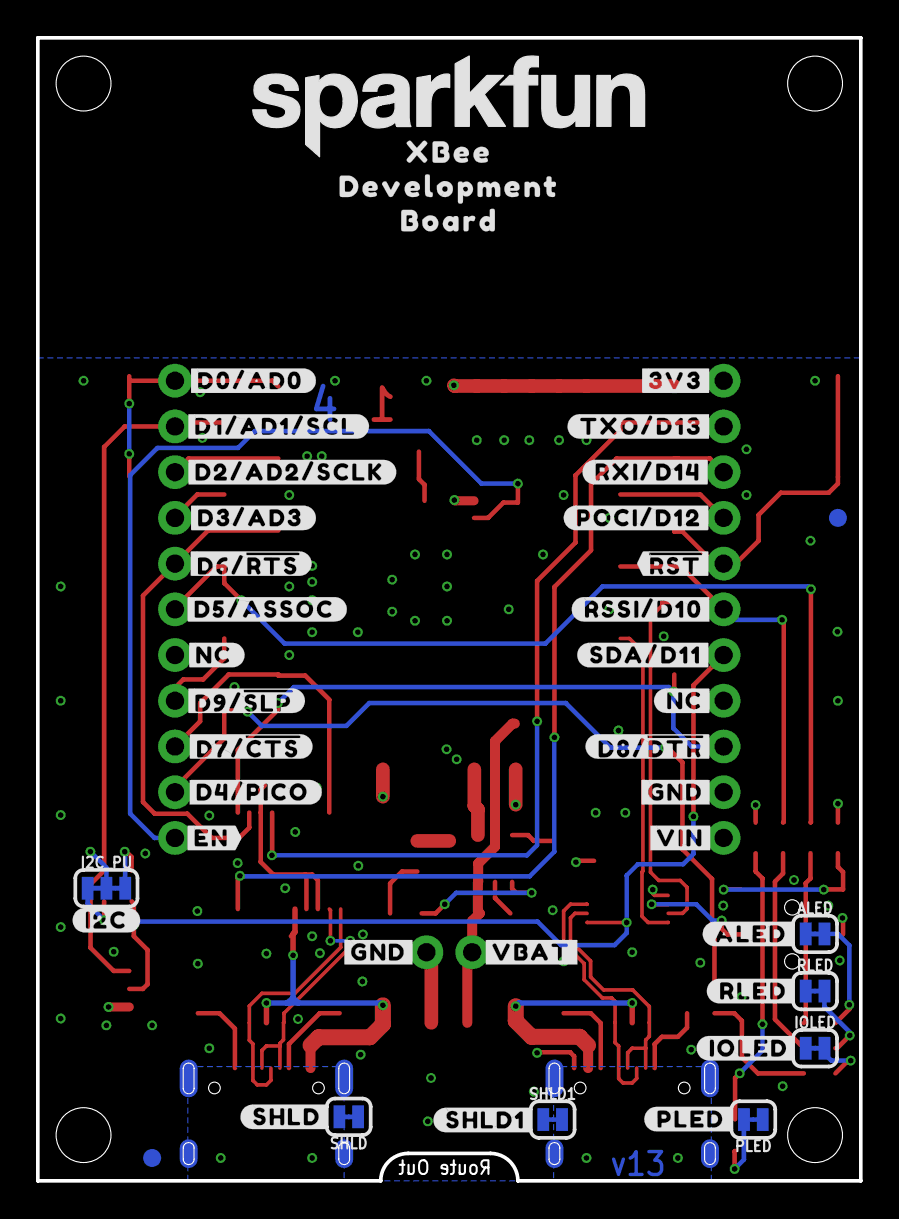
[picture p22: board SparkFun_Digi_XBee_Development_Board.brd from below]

Board: 4 copper layers, 45.7 x 63.5 mm, 150 parts (44 on the bottom side), 55 nets.

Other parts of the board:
U$1: #D2#AD2#SCLK#19
U$2, U$17: ##RST##15
U$3: ##CS##19
U$4: ##CTS##25
U$5: ##DTR##27
U$6: #D1#AD1#SCL#8
U$7: ##RTS##24
U$8, U$21: #EN#17
U$9, U$44: #3V3#1
U$10: #D0#18
U$11, U$37: #VBAT#5
U$12: #D3#AD3#22
U$13: #D4#PICO#24
U$14: #POCI#D12#24
U$15: #TXO#D13#13
U$16: #RXI#D14#15
U$18: #RSSI#D10#17
U$19: CHG47
U$20, U$25, U$38, U$45: #GND#0
U$22: #SDA#D11#8
U$23, U$50: XBEE339
U$24, U$67: #NC#1
U$26: #I2C#33
U$27: #ALED#21
U$28: #PICO#23
U$29: #POCI#23
U$30: #RST#30
U$31: #RSSI#16
U$32: #DUSB#31
U$33: IO46
U$34: #SDA#7
U$35: #SHLD#740
U$36: #SHLD1#741
U$39: #D5#3
U$40: D03
U$41, U$46: #VIN#4
U$42: PWR26
U$43: ASC32
U$47: ##SLP##27
U$48, U$66: #NC#3
U$49: #I2C#31
U$51, U$70: DEVELOPMENT1345
U$52, U$71: BOARD1346
U$53: #D8##DTR##27
U$54: #PLED#20
U$55: #D0#AD0#18
U$56: #D5#ASSOC#24
U$57: #D6##RTS##24
U$58: #D7##CTS##25
U$59: #IOLED#23
U$60: #D9##SLP##27
U$61: SFE_LOGO_FLAME_.2
U$62: RSSI31
U$63: SFE_LOGO_NAME_.2
U$64: #RLED#22
U$65: UART32
U$68: DIRECT_USB33

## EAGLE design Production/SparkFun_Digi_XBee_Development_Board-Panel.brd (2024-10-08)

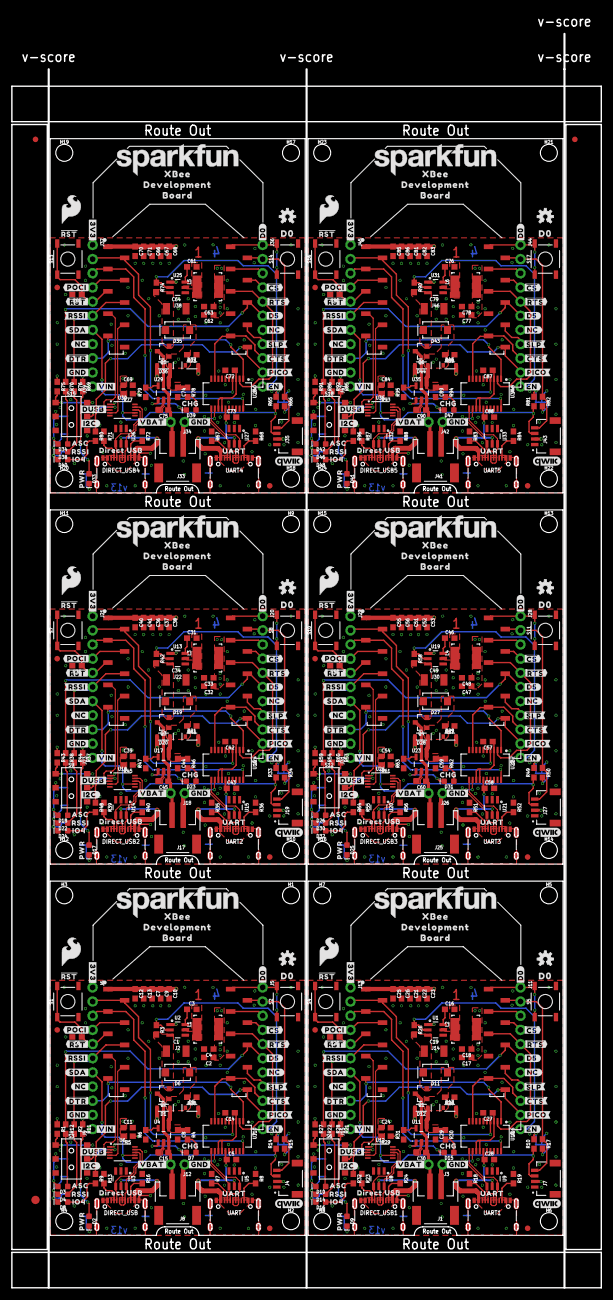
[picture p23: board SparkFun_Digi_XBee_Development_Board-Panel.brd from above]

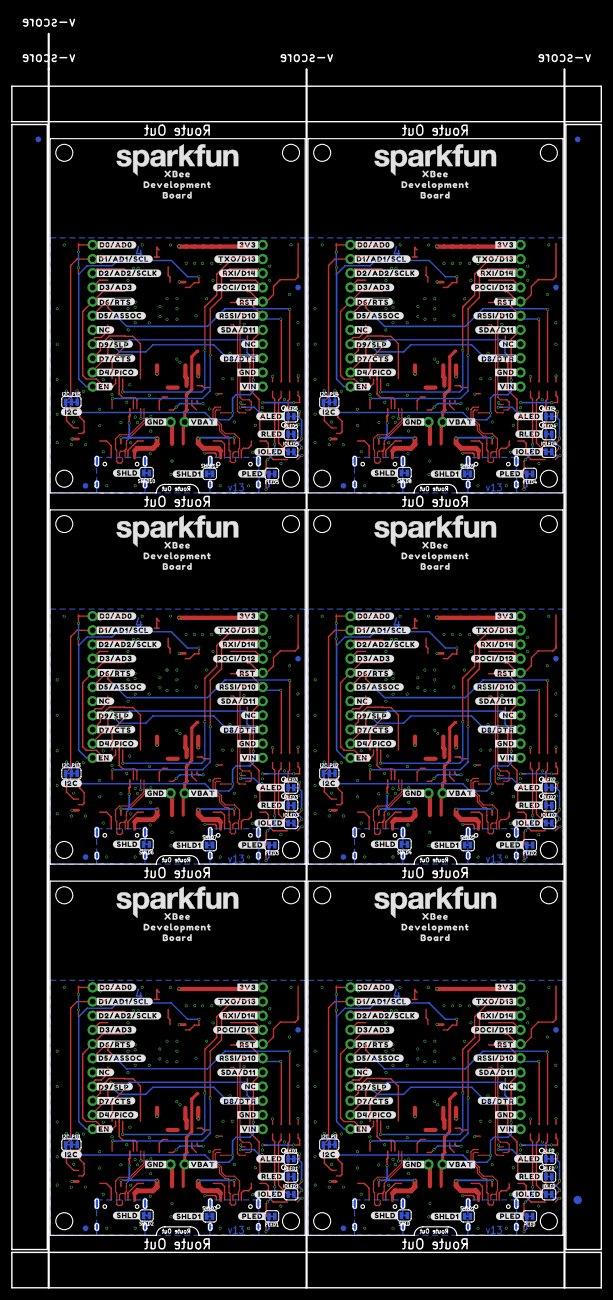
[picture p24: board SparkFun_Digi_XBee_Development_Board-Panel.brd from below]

Board: 4 copper layers, 105.7 x 224.8 mm, 894 parts (267 on the bottom side), 330 nets.

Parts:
ALED, ALED1, ALED2, ALED3, ALED4, ALED5: JUMPER-SMT_2_NC_TRACE_SILK; SMT-JUMPER_2_NC_TRACE_SILK
C1, C19, C34, C49, C64, C79: 10uF; 1210
C2, C4, C17, C18, C32, C33, C47, C48, C62, C63, C77, C78: 22uF; 0603
C3, C5, C9, C11, C14, C16, C22, C24, C27, C28, C31, C37, C39, C42, C43, C46, C52, C54, C57, C58, C61, C67, C69, C72, C73, C76, C82, C84, C87, C88: 0.1uF; 0603
C6, C7, C20, C21, C35, C36, C50, C51, C65, C66, C80, C81: 10nF; 0603
C8, C15, C29, C30, C44, C45, C59, C60, C74, C75, C89, C90: 4.7uF; 0603
C10, C23, C38, C53, C68, C83: 10uF; 0603
C12, C25, C40, C55, C70, C85: 10pF; 0603
C13, C26, C41, C56, C71, C86: 47pF; 0603
D1, D5, D12, D13, D20, D21, D28, D29, D36, D37, D44, D45: 3A/10V/280mV; SOD-323
D2, D9, D17, D25, D33, D41: RED; LED-0603
D3, D10, D18, D26, D34, D42: BLUE; LED-0603
D4, D7, D14, D15, D22, D23, D30, D31, D38, D39, D46, D47: Yellow; LED-0603
D6, D11, D19, D27, D35, D43: 3A/40V/500mV; SMA-DIODE
D8, D16, D24, D32, D40, D48: GREEN; LED-0603
DIRECT_USB, DIRECT_USB1, DIRECT_USB2, DIRECT_USB3, DIRECT_USB4, DIRECT_USB5: USB Female Type C Connector; USB-C-16P-4LAYER-ISOLATED
E$1, E$2, E$3, E$4: FIDUCIAL-1X2
E$5, E$6: FIDUCIAL-1.5X3
FD1, FD2, FD3, FD4, FD5, FD6, FD7, FD8, FD9, FD10, FD11, FD12, FD13, FD14, FD15, FD16, FD17, FD18, FD19, FD20, FD21, FD22, FD23, FD24: FIDUCIAL1X2; FIDUCIAL-1X2
H1, H2, H3, H4, H5, H6, H7, H8, H9, H10, H11, H12, H13, H14, H15, H16, H17, H18, H19, H20, H21, H22, H23, H24: STAND-OFFTIGHT; STAND-OFF-TIGHT
I2C_PU, I2C_PU1, I2C_PU2, I2C_PU3, I2C_PU4, I2C_PU5: JUMPER-SMT_3_2-NC_TRACE_SILK; SMT-JUMPER_3_2-NC_TRACE_SILK
IOLED, IOLED1, IOLED2, IOLED3, IOLED4, IOLED5: JUMPER-SMT_2_NC_TRACE_SILK; SMT-JUMPER_2_NC_TRACE_SILK
J1, J8, J17, J25, J33, J41: JST-2-SMD
J2, J14, J22, J30, J38, J46: XBEE3-SMD
J3, J12, J18, J26, J34, J42: 1X02_NO_SILK
J4, J7, J19, J27, J35, J43: QWIIC_RIGHT_ANGLE; JST04_1MM_RA
J5, J6, J11, J13, J20, J21, J28, J29, J36, J37, J44, J45: 1X10_NO_SILK
J9, J10, J15, J16, J23, J24, J31, J32, J39, J40, J47, J48: 1X01_NO_SILK_STAND
L1, L2, L3, L4, L5, L6: 3.9UH; INDUCTOR_3.9UH
LOGO1, LOGO6, LOGO9, LOGO12, LOGO15, LOGO18: SFE_LOGO_NAME.2_INCH; SFE_LOGO_NAME_.2
LOGO2, LOGO4, LOGO7, LOGO10, LOGO13, LOGO16: OSHW-LOGOS; OSHW-LOGO-S
LOGO3, LOGO5, LOGO8, LOGO11, LOGO14, LOGO17: QWIIC_LOGO_5MM; QWIIC_5MM
PLED, PLED1, PLED2, PLED3, PLED4, PLED5: JUMPER-SMT_2_NC_TRACE_SILK; SMT-JUMPER_2_NC_TRACE_SILK
Q1, Q2, Q3, Q4, Q5, Q6: 3.1A/30V/105mΩ; SOT23-3
R1, R27, R43, R59, R75, R91: 100k; 0603
R2, R10, R12, R14, R15, R17, R22, R28, R33, R34, R38, R44, R49, R50, R54, R60, R65, R66, R70, R76, R81, R82, R86, R92: 2.2k; 0603
R3, R20, R25, R26, R41, R42, R57, R58, R73, R74, R89, R90: 10k; 0603
R4, R11, R21, R30, R37, R46, R53, R62, R69, R78, R85, R94: 4.7k; 0603
R5, R29, R45, R61, R77, R93: 0; 0603
R6, R31, R47, R63, R79, R95: 2.0k; 0603
R7, R8, R13, R16, R18, R19, R23, R24, R35, R36, R39, R40, R51, R52, R55, R56, R67, R68, R71, R72, R83, R84, R87, R88: 5.1k; 0603
R9, R32, R48, R64, R80, R96: 330; 0603
RLED, RLED1, RLED2, RLED3, RLED4, RLED5: JUMPER-SMT_2_NC_TRACE_SILK; SMT-JUMPER_2_NC_TRACE_SILK
S1, S2, S4, S5, S7, S8, S10, S11, S13, S14, S16, S17: TACTILE_SWITCH_SMD_5.2MM
S3, S6, S9, S12, S15, S18: SWITCH_DPDT_SMD_AYZ0202
SHLD, SHLD1, SHLD2, SHLD3, SHLD4, SHLD5, SHLD6, SHLD7, SHLD8, SHLD9, SHLD10, SHLD11: JUMPER-SMT_2_NC_TRACE_SILK; SMT-JUMPER_2_NC_TRACE_SILK
U1, U2, U13, U19, U25, U31: AP63203; SOT23-6
U3, U5, U8, U9, U14, U15, U20, U21, U26, U27, U32, U33: ESD Diode; SOT-23-6
U4, U11, U17, U23, U29, U35: MCP73831; SOT23-5
U6, U12, U18, U24, U30, U36: FSUSB42MUX; MSOP10
U7, U10, U16, U22, U28, U34: FT231XS; SSOP20_L
U$1, U$135, U$205, U$275, U$345, U$415: #D2#AD2#SCLK#19
U$2, U$17, U$91, U$104, U$161, U$174, U$231, U$244, U$301, U$314, U$371, U$384: ##RST##15
U$3, U$69, U$141, U$211, U$281, U$351: ##CS##19
U$4, U$72, U$142, U$212, U$282, U$352: ##CTS##25
U$5, U$117, U$187, U$257, U$327, U$397: ##DTR##27
U$6, U$132, U$202, U$272, U$342, U$412: #D1#AD1#SCL#8
U$7, U$73, U$143, U$213, U$283, U$353: ##RTS##24
U$8, U$21, U$118, U$119, U$188, U$189, U$258, U$259, U$328, U$329, U$398, U$399: #EN#17
U$9, U$44, U$74, U$85, U$144, U$155, U$214, U$225, U$284, U$295, U$354, U$365: #3V3#1
U$10, U$75, U$145, U$215, U$285, U$355: #D0#18
U$11, U$37, U$92, U$107, U$162, U$177, U$232, U$247, U$302, U$317, U$372, U$387: #VBAT#5
U$12, U$96, U$166, U$236, U$306, U$376: #D3#AD3#22
U$13, U$97, U$167, U$237, U$307, U$377: #D4#PICO#24
U$14, U$115, U$185, U$255, U$325, U$395: #POCI#D12#24
U$15, U$102, U$172, U$242, U$312, U$382: #TXO#D13#13
U$16, U$103, U$173, U$243, U$313, U$383: #RXI#D14#15
U$18, U$105, U$175, U$245, U$315, U$385: #RSSI#D10#17
U$19, U$136, U$206, U$276, U$346, U$416: CHG47
U$20, U$25, U$38, U$45, U$76, U$81, U$86, U$108, U$146, U$151, U$156, U$178, U$216, U$221, U$226, U$248, U$286, U$291, U$296, U$318, U$356, U$361, U$366, U$388: #GND#0
U$22, U$106, U$176, U$246, U$316, U$386: #SDA#D11#8
U$23, U$50, U$130, U$131, U$200, U$201, U$270, U$271, U$340, U$341, U$410, U$411: XBEE339
U$24, U$67, U$120, U$123, U$190, U$193, U$260, U$263, U$330, U$333, U$400, U$403: #NC#1
U$26, U$77, U$147, U$217, U$287, U$357: #I2C#33
U$27, U$93, U$163, U$233, U$303, U$373: #ALED#21
U$28, U$78, U$148, U$218, U$288, U$358: #PICO#23
U$29, U$116, U$186, U$256, U$326, U$396: #POCI#23
U$30, U$110, U$180, U$250, U$320, U$390: #RST#30
U$31, U$79, U$149, U$219, U$289, U$359: #RSSI#16
U$32, U$129, U$199, U$269, U$339, U$409: #DUSB#31
U$33, U$137, U$207, U$277, U$347, U$417: IO46
U$34, U$80, U$150, U$220, U$290, U$360: #SDA#7
U$35, U$138, U$208, U$278, U$348, U$418: #SHLD#740
U$36, U$139, U$209, U$279, U$349, U$419: #SHLD1#741
U$39, U$82, U$152, U$222, U$292, U$362: #D5#3
U$40, U$90, U$160, U$230, U$300, U$370: D03
U$41, U$46, U$83, U$87, U$153, U$157, U$223, U$227, U$293, U$297, U$363, U$367: #VIN#4
U$42, U$84, U$154, U$224, U$294, U$364: PWR26
U$43, U$134, U$204, U$274, U$344, U$414: ASC32
U$47, U$88, U$158, U$228, U$298, U$368: ##SLP##27
U$48, U$66, U$121, U$122, U$191, U$192, U$261, U$262, U$331, U$332, U$401, U$402: #NC#3
U$49, U$89, U$159, U$229, U$299, U$369: #I2C#31
U$51, U$70, U$125, U$127, U$195, U$197, U$265, U$267, U$335, U$337, U$405, U$407: DEVELOPMENT1345
U$52, U$71, U$126, U$128, U$196, U$198, U$266, U$268, U$336, U$338, U$406, U$408: BOARD1346
U$53, U$133, U$203, U$273, U$343, U$413: #D8##DTR##27
U$54, U$94, U$164, U$234, U$304, U$374: #PLED#20
U$55, U$95, U$165, U$235, U$305, U$375: #D0#AD0#18
U$56, U$98, U$168, U$238, U$308, U$378: #D5#ASSOC#24
U$57, U$99, U$169, U$239, U$309, U$379: #D6##RTS##24
U$58, U$100, U$170, U$240, U$310, U$380: #D7##CTS##25
U$59, U$140, U$210, U$280, U$350, U$420: #IOLED#23
U$60, U$101, U$171, U$241, U$311, U$381: #D9##SLP##27
U$61, U$112, U$182, U$252, U$322, U$392: SFE_LOGO_FLAME_.2
U$62, U$113, U$183, U$253, U$323, U$393: RSSI31
U$63, U$111, U$181, U$251, U$321, U$391: SFE_LOGO_NAME_.2
U$64, U$114, U$184, U$254, U$324, U$394: #RLED#22
U$65, U$109, U$179, U$249, U$319, U$389: UART32
U$68, U$124, U$194, U$264, U$334, U$404: DIRECT_USB33
UART, UART1, UART2, UART3, UART4, UART5: USB Female Type C Connector; USB-C-16P-4LAYER-ISOLATED

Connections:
3.3V: C2.1, C4.1, C7.1, C9.1, C10.1, C11.1, C12.1, C13.1, I2C_PU.2, J2.1, J4.2, J6.1, L1.P$2, R1.1, R5.2, R11.1, U2.1
3.3V1: C17.1, C18.1, C21.1, C22.1, C23.1, C24.1, C25.1, C26.1, I2C_PU1.2, J7.2, J13.1, J14.1, L2.P$2, R21.1, R27.1, R29.2, U1.1
3.3V2: C32.1, C33.1, C36.1, C37.1, C38.1, C39.1, C40.1, C41.1, I2C_PU2.2, J19.2, J21.1, J22.1, L3.P$2, R37.1, R43.1, R45.2, U13.1
3.3V3: C47.1, C48.1, C51.1, C52.1, C53.1, C54.1, C55.1, C56.1, I2C_PU3.2, J27.2, J29.1, J30.1, L4.P$2, R53.1, R59.1, R61.2, U19.1
3.3V4: C62.1, C63.1, C66.1, C67.1, C68.1, C69.1, C70.1, C71.1, I2C_PU4.2, J35.2, J37.1, J38.1, L5.P$2, R69.1, R75.1, R77.2, U25.1
3.3V5: C77.1, C78.1, C81.1, C82.1, C83.1, C84.1, C85.1, C86.1, I2C_PU5.2, J43.2, J45.1, J46.1, L6.P$2, R85.1, R91.1, R93.2, U31.1
!RESET!: C6.1, J2.5, J6.5, S1.1, S1.2
!RESET!1: C20.1, J13.5, J14.5, S4.1, S4.2
!RESET!2: C35.1, J21.5, J22.5, S7.1, S7.2
!RESET!3: C50.1, J29.5, J30.5, S10.1, S10.2
!RESET!4: C65.1, J37.5, J38.5, S13.1, S13.2
!RESET!5: C80.1, J45.5, J46.5, S16.1, S16.2
ALED: ALED.2, D3.C
ALED1: ALED1.2, D10.C
ALED2: ALED2.2, D18.C
ALED3: ALED3.2, D26.C
ALED4: ALED4.2, D34.C
ALED5: ALED5.2, D42.C
D0: J2.20, J5.1, S2.1, S2.2
D1: J11.1, J14.20, S5.1, S5.2
D1/SCL: J2.19, J4.4, J5.2, R15.1
D1/SCL1: J7.4, J11.2, J14.19, R17.1
D1/SCL2: J19.4, J20.2, J22.19, R34.1
D1/SCL3: J27.4, J28.2, J30.19, R50.1
D1/SCL4: J35.4, J36.2, J38.19, R66.1
D1/SCL5: J43.4, J44.2, J46.19, R82.1
D2: J20.1, J22.20, S8.1, S8.2
D2/SPI_CLK: J2.18, J5.3
D2/SPI_CLK1: J11.3, J14.18
D2/SPI_CLK2: J20.3, J22.18
D2/SPI_CLK3: J28.3, J30.18
D2/SPI_CLK4: J36.3, J38.18
D2/SPI_CLK5: J44.3, J46.18
D3: J28.1, J30.20, S11.1, S11.2
D3/SPI_!CS!: J2.17, J5.4
D3/SPI_!CS!1: J11.4, J14.17
D3/SPI_!CS!2: J20.4, J22.17
D3/SPI_!CS!3: J28.4, J30.17
D3/SPI_!CS!4: J36.4, J38.17
D3/SPI_!CS!5: J44.4, J46.17
D4: J36.1, J38.20, S14.1, S14.2
D4/SPI_PICO: J2.11, J5.10, R9.1
D4/SPI_PICO1: J11.10, J14.11, R32.1
D4/SPI_PICO2: J20.10, J22.11, R48.1
D4/SPI_PICO3: J28.10, J30.11, R64.1
D4/SPI_PICO4: J36.10, J38.11, R80.1
D4/SPI_PICO5: J44.10, J46.11, R96.1
D5: J44.1, J46.20, S17.1, S17.2
D5/ASSOCIATE: J2.15, J5.6, R12.1
D5/ASSOCIATE1: J11.6, J14.15, R22.1
D5/ASSOCIATE2: J20.6, J22.15, R38.1
D5/ASSOCIATE3: J28.6, J30.15, R54.1
D5/ASSOCIATE4: J36.6, J38.15, R70.1
D5/ASSOCIATE5: J44.6, J46.15, R86.1
D6/!RTS!: J2.16, J5.5, U7.2
D6/!RTS!1: J11.5, J14.16, U10.2
D6/!RTS!2: J20.5, J22.16, U16.2
D6/!RTS!3: J28.5, J30.16, U22.2
D6/!RTS!4: J36.5, J38.16, U28.2
D6/!RTS!5: J44.5, J46.16, U34.2
D7/!CTS!: J2.12, J5.9, U7.9
D7/!CTS!1: J11.9, J14.12, U10.9
D7/!CTS!2: J20.9, J22.12, U16.9
D7/!CTS!3: J28.9, J30.12, U22.9
D7/!CTS!4: J36.9, J38.12, U28.9
D7/!CTS!5: J44.9, J46.12, U34.9
D8/!DTR!: J2.9, J6.9, U7.1
D8/!DTR!1: J13.9, J14.9, U10.1
D8/!DTR!2: J21.9, J22.9, U16.1
D8/!DTR!3: J29.9, J30.9, U22.1
D8/!DTR!4: J37.9, J38.9, U28.1
D8/!DTR!5: J45.9, J46.9, U34.1
D9/!SLEEP!: J2.13, J5.8
D9/!SLEEP!1: J11.8, J14.13
D9/!SLEEP!2: J20.8, J22.13
D9/!SLEEP!3: J28.8, J30.13
D9/!SLEEP!4: J36.8, J38.13
D9/!SLEEP!5: J44.8, J46.13
D10/RSSI_PWM: J2.6, J6.6, R2.1
D10/RSSI_PWM1: J13.6, J14.6, R28.1
D10/RSSI_PWM2: J21.6, J22.6, R44.1
D10/RSSI_PWM3: J29.6, J30.6, R60.1
D10/RSSI_PWM4: J37.6, J38.6, R76.1
D10/RSSI_PWM5: J45.6, J46.6, R92.1
D11/SDA: J4.3, J6.7, R14.1, U6.7
D11/SDA1: J7.3, J13.7, R10.1, U12.7
D11/SDA2: J19.3, J21.7, R33.1, U18.7
D11/SDA3: J27.3, J29.7, R49.1, U24.7
D11/SDA4: J35.3, J37.7, R65.1, U30.7
D11/SDA5: J43.3, J45.7, R81.1, U36.7
D12/SPI_POCI: J2.4, J6.4
D12/SPI_POCI1: J13.4, J14.4
D12/SPI_POCI2: J21.4, J22.4
D12/SPI_POCI3: J29.4, J30.4
D12/SPI_POCI4: J37.4, J38.4
D12/SPI_POCI5: J45.4, J46.4
D13/TXO: J2.2, J6.2, U7.4
D13/TXO1: J13.2, J14.2, U10.4
D13/TXO2: J21.2, J22.2, U16.4
D13/TXO3: J29.2, J30.2, U22.4
D13/TXO4: J37.2, J38.2, U28.4
D13/TXO5: J45.2, J46.2, U34.4
D14/RXI: J2.3, J6.3, U7.20
D14/RXI1: J13.3, J14.3, U10.20
D14/RXI2: J21.3, J22.3, U16.20
D14/RXI3: J29.3, J30.3, U22.20
D14/RXI4: J37.3, J38.3, U28.20
D14/RXI5: J45.3, J46.3, U34.20
D+: U5.6, U7.11, UART.A6, UART.B6
D+1: U9.6, U10.11, UART1.A6, UART1.B6
D+2: U15.6, U16.11, UART2.A6, UART2.B6
D+3: U21.6, U22.11, UART3.A6, UART3.B6
D+4: U27.6, U28.11, UART4.A6, UART4.B6
D+5: U33.6, U34.11, UART5.A6, UART5.B6
D-: U5.4, U7.12, UART.A7, UART.B7
D-1: U9.4, U10.12, UART1.A7, UART1.B7
D-2: U15.4, U16.12, UART2.A7, UART2.B7
D-3: U21.4, U22.12, UART3.A7, UART3.B7
D-4: U27.4, U28.12, UART4.A7, UART4.B7
D-5: U33.4, U34.12, UART5.A7, UART5.B7
DIRECT_D+: DIRECT_USB.A6, DIRECT_USB.B6, U3.6, U6.9
DIRECT_D+1: DIRECT_USB1.A6, DIRECT_USB1.B6, U8.6, U12.9
DIRECT_D+2: DIRECT_USB2.A6, DIRECT_USB2.B6, U14.6, U18.9
DIRECT_D+3: DIRECT_USB3.A6, DIRECT_USB3.B6, U20.6, U24.9
DIRECT_D+4: DIRECT_USB4.A6, DIRECT_USB4.B6, U26.6, U30.9
DIRECT_D+5: DIRECT_USB5.A6, DIRECT_USB5.B6, U32.6, U36.9
DIRECT_D-: DIRECT_USB.A7, DIRECT_USB.B7, U3.4, U6.8
DIRECT_D-1: DIRECT_USB1.A7, DIRECT_USB1.B7, U8.4, U12.8
DIRECT_D-2: DIRECT_USB2.A7, DIRECT_USB2.B7, U14.4, U18.8
DIRECT_D-3: DIRECT_USB3.A7, DIRECT_USB3.B7, U20.4, U24.8
DIRECT_D-4: DIRECT_USB4.A7, DIRECT_USB4.B7, U26.4, U30.8
DIRECT_D-5: DIRECT_USB5.A7, DIRECT_USB5.B7, U32.4, U36.8
DIRECT_SELECT: S3.2, S3.5, U6.2
DIRECT_SELECT1: S6.2, S6.5, U12.2
DIRECT_SELECT2: S9.2, S9.5, U18.2
DIRECT_SELECT3: S12.2, S12.5, U24.2
DIRECT_SELECT4: S15.2, S15.5, U30.2
DIRECT_SELECT5: S18.2, S18.5, U36.2
EN: J10.1, R3.1, U2.2
EN1: J16.1, R26.1, U1.2
EN2: J24.1, R42.1, U13.2
EN3: J32.1, R58.1, U19.2
EN4: J40.1, R74.1, U25.2
EN5: J48.1, R90.1, U31.2
FIRMWARE: R1.2, S3.1, S3.4
FIRMWARE1: R27.2, S6.1, S6.4
FIRMWARE2: R43.2, S9.1, S9.4
FIRMWARE3: R59.2, S12.1, S12.4
FIRMWARE4: R75.2, S15.1, S15.4
FIRMWARE5: R91.2, S18.1, S18.4
GND: ALED.1, C1.2, C2.2, C4.2, C5.2, C6.2, C7.2, C8.2, C9.2, C10.2, C11.2, C12.2, C13.2, C14.2, C15.2, DIRECT_USB.GND, DIRECT_USB.GND2, IOLED.1, J2.10, J4.1, J6.10, J8.1, J12.1, PLED.1, R6.1, R7.1, R8.1, R13.1, R16.1, R20.1, RLED.1, S1.3, S1.4, S2.3, S2.4, S3.3, S3.6, SHLD.1, SHLD1.1, U2.4, U3.2, U4.2, U5.2, U6.5, U6.10, U7.6, U7.16, UART.GND, UART.GND2
GND1: ALED1.1, C17.2, C18.2, C19.2, C20.2, C21.2, C22.2, C23.2, C24.2, C25.2, C26.2, C27.2, C28.2, C29.2, C30.2, DIRECT_USB1.GND, DIRECT_USB1.GND2, IOLED1.1, J1.1, J3.1, J7.1, J13.10, J14.10, PLED1.1, R18.1, R19.1, R23.1, R24.1, R25.1, R31.1, RLED1.1, S4.3, S4.4, S5.3, S5.4, S6.3, S6.6, SHLD2.1, SHLD3.1, U1.4, U8.2, U9.2, U10.6, U10.16, U11.2, U12.5, U12.10, UART1.GND, UART1.GND2
GND2: ALED2.1, C32.2, C33.2, C34.2, C35.2, C36.2, C37.2, C38.2, C39.2, C40.2, C41.2, C42.2, C43.2, C44.2, C45.2, DIRECT_USB2.GND, DIRECT_USB2.GND2, IOLED2.1, J17.1, J18.1, J19.1, J21.10, J22.10, PLED2.1, R35.1, R36.1, R39.1, R40.1, R41.1, R47.1, RLED2.1, S7.3, S7.4, S8.3, S8.4, S9.3, S9.6, SHLD4.1, SHLD5.1, U13.4, U14.2, U15.2, U16.6, U16.16, U17.2, U18.5, U18.10, UART2.GND, UART2.GND2
GND3: ALED3.1, C47.2, C48.2, C49.2, C50.2, C51.2, C52.2, C53.2, C54.2, C55.2, C56.2, C57.2, C58.2, C59.2, C60.2, DIRECT_USB3.GND, DIRECT_USB3.GND2, IOLED3.1, J25.1, J26.1, J27.1, J29.10, J30.10, PLED3.1, R51.1, R52.1, R55.1, R56.1, R57.1, R63.1, RLED3.1, S10.3, S10.4, S11.3, S11.4, S12.3, S12.6, SHLD6.1, SHLD7.1, U19.4, U20.2, U21.2, U22.6, U22.16, U23.2, U24.5, U24.10, UART3.GND, UART3.GND2
GND4: ALED4.1, C62.2, C63.2, C64.2, C65.2, C66.2, C67.2, C68.2, C69.2, C70.2, C71.2, C72.2, C73.2, C74.2, C75.2, DIRECT_USB4.GND, DIRECT_USB4.GND2, IOLED4.1, J33.1, J34.1, J35.1, J37.10, J38.10, PLED4.1, R67.1, R68.1, R71.1, R72.1, R73.1, R79.1, RLED4.1, S13.3, S13.4, S14.3, S14.4, S15.3, S15.6, SHLD8.1, SHLD9.1, U25.4, U26.2, U27.2, U28.6, U28.16, U29.2, U30.5, U30.10, UART4.GND, UART4.GND2
GND5: ALED5.1, C77.2, C78.2, C79.2, C80.2, C81.2, C82.2, C83.2, C84.2, C85.2, C86.2, C87.2, C88.2, C89.2, C90.2, DIRECT_USB5.GND, DIRECT_USB5.GND2, IOLED5.1, J41.1, J42.1, J43.1, J45.10, J46.10, PLED5.1, R83.1, R84.1, R87.1, R88.1, R89.1, R95.1, RLED5.1, S16.3, S16.4, S17.3, S17.4, S18.3, S18.6, SHLD10.1, SHLD11.1, U31.4, U32.2, U33.2, U34.6, U34.16, U35.2, U36.5, U36.10, UART5.GND, UART5.GND2
IOLED: D8.C, IOLED.2
IOLED1: D16.C, IOLED1.2
IOLED2: D24.C, IOLED2.2
IOLED3: D32.C, IOLED3.2
IOLED4: D40.C, IOLED4.2
IOLED5: D48.C, IOLED5.2
unnamed: C3.1, U2.6
unnamed: D4.A, R2.2
unnamed: R5.1, U6.1
unnamed: R8.2, UART.B5
unnamed: R7.2, UART.A5
unnamed: R6.2, U4.5
unnamed: D2.A, R11.2
unnamed: C3.2, L1.P$1, U2.5
unnamed: D7.C, U4.1
unnamed: D7.A, R4.2
unnamed: I2C_PU.3, R14.2
unnamed: D3.A, R12.2
unnamed: I2C_PU.1, R15.2
unnamed: DIRECT_USB.B5, R16.2
unnamed: C1.1, D6.C, Q2.2, R3.2, U2.3
unnamed: DIRECT_USB.A5, R13.2
unnamed: D8.A, R9.2
unnamed: C14.1, U7.3, U7.13, U7.14
unnamed: I2C_PU1.3, R10.2
unnamed: I2C_PU1.1, R17.2
unnamed: R19.2, UART1.B5
unnamed: R18.2, UART1.A5
unnamed: D9.A, R21.2
unnamed: D10.A, R22.2
unnamed: DIRECT_USB1.B5, R24.2
unnamed: DIRECT_USB1.A5, R23.2
unnamed: C19.1, D11.C, Q1.2, R26.2, U1.3
unnamed: C16.1, U1.6
unnamed: C16.2, L2.P$1, U1.5
unnamed: D14.A, R28.2
unnamed: R29.1, U12.1
unnamed: R31.2, U11.5
unnamed: D15.C, U11.1
unnamed: D15.A, R30.2
unnamed: D16.A, R32.2
unnamed: C27.1, U10.3, U10.13, U10.14
unnamed: I2C_PU2.3, R33.2
unnamed: I2C_PU2.1, R34.2
unnamed: R36.2, UART2.B5
unnamed: R35.2, UART2.A5
unnamed: D17.A, R37.2
unnamed: D18.A, R38.2
unnamed: DIRECT_USB2.B5, R40.2
unnamed: DIRECT_USB2.A5, R39.2
unnamed: C34.1, D19.C, Q3.2, R42.2, U13.3
unnamed: C31.1, U13.6
unnamed: C31.2, L3.P$1, U13.5
unnamed: D22.A, R44.2
unnamed: R45.1, U18.1
unnamed: R47.2, U17.5
unnamed: D23.C, U17.1
unnamed: D23.A, R46.2
unnamed: D24.A, R48.2
unnamed: C42.1, U16.3, U16.13, U16.14
unnamed: I2C_PU3.3, R49.2
unnamed: I2C_PU3.1, R50.2
unnamed: R52.2, UART3.B5
unnamed: R51.2, UART3.A5
unnamed: D25.A, R53.2
unnamed: D26.A, R54.2
unnamed: DIRECT_USB3.B5, R56.2
unnamed: DIRECT_USB3.A5, R55.2
unnamed: C49.1, D27.C, Q4.2, R58.2, U19.3
unnamed: C46.1, U19.6
unnamed: C46.2, L4.P$1, U19.5
unnamed: D30.A, R60.2
unnamed: R61.1, U24.1
unnamed: R63.2, U23.5
unnamed: D31.C, U23.1
unnamed: D31.A, R62.2
unnamed: D32.A, R64.2
unnamed: C57.1, U22.3, U22.13, U22.14
unnamed: I2C_PU4.3, R65.2
unnamed: I2C_PU4.1, R66.2
unnamed: R68.2, UART4.B5
unnamed: R67.2, UART4.A5
unnamed: D33.A, R69.2
unnamed: D34.A, R70.2
unnamed: DIRECT_USB4.B5, R72.2
unnamed: DIRECT_USB4.A5, R71.2
unnamed: C64.1, D35.C, Q5.2, R74.2, U25.3
unnamed: C61.1, U25.6
unnamed: C61.2, L5.P$1, U25.5
unnamed: D38.A, R76.2
unnamed: R77.1, U30.1
unnamed: R79.2, U29.5
unnamed: D39.C, U29.1
unnamed: D39.A, R78.2
unnamed: D40.A, R80.2
unnamed: C72.1, U28.3, U28.13, U28.14
unnamed: I2C_PU5.3, R81.2
unnamed: I2C_PU5.1, R82.2
unnamed: R84.2, UART5.B5
unnamed: R83.2, UART5.A5
unnamed: D41.A, R85.2
unnamed: D42.A, R86.2
unnamed: DIRECT_USB5.B5, R88.2
unnamed: DIRECT_USB5.A5, R87.2
unnamed: C79.1, D43.C, Q6.2, R90.2, U31.3
unnamed: C76.1, U31.6
unnamed: C76.2, L6.P$1, U31.5
unnamed: D46.A, R92.2
unnamed: R93.1, U36.1
unnamed: R95.2, U35.5
unnamed: D47.C, U35.1
unnamed: D47.A, R94.2
unnamed: D48.A, R96.2
unnamed: C87.1, U34.3, U34.13, U34.14
PLED: D2.C, PLED.2
PLED1: D9.C, PLED1.2
PLED2: D17.C, PLED2.2
PLED3: D25.C, PLED3.2
PLED4: D33.C, PLED4.2
PLED5: D41.C, PLED5.2
RLED: D4.C, RLED.2
RLED1: D14.C, RLED1.2
RLED2: D22.C, RLED2.2
RLED3: D30.C, RLED3.2
RLED4: D38.C, RLED4.2
RLED5: D46.C, RLED5.2
SHLD: SHLD.2, UART.SHLD1, UART.SHLD2, UART.SHLD3, UART.SHLD4, UART.SHLD5, UART.SHLD6, UART.SHLD7, UART.SHLD8
SHLD1: DIRECT_USB.SHLD1, DIRECT_USB.SHLD2, DIRECT_USB.SHLD3, DIRECT_USB.SHLD4, DIRECT_USB.SHLD5, DIRECT_USB.SHLD6, DIRECT_USB.SHLD7, DIRECT_USB.SHLD8, SHLD1.2
SHLD2: SHLD2.2, UART1.SHLD1, UART1.SHLD2, UART1.SHLD3, UART1.SHLD4, UART1.SHLD5, UART1.SHLD6, UART1.SHLD7, UART1.SHLD8
SHLD3: DIRECT_USB1.SHLD1, DIRECT_USB1.SHLD2, DIRECT_USB1.SHLD3, DIRECT_USB1.SHLD4, DIRECT_USB1.SHLD5, DIRECT_USB1.SHLD6, DIRECT_USB1.SHLD7, DIRECT_USB1.SHLD8, SHLD3.2
SHLD4: SHLD4.2, UART2.SHLD1, UART2.SHLD2, UART2.SHLD3, UART2.SHLD4, UART2.SHLD5, UART2.SHLD6, UART2.SHLD7, UART2.SHLD8
SHLD5: DIRECT_USB2.SHLD1, DIRECT_USB2.SHLD2, DIRECT_USB2.SHLD3, DIRECT_USB2.SHLD4, DIRECT_USB2.SHLD5, DIRECT_USB2.SHLD6, DIRECT_USB2.SHLD7, DIRECT_USB2.SHLD8, SHLD5.2
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

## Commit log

2023-01-04 Adds higher current capable switching regulator
    [XBee_Explorer Thin.brd, XBee_Explorer Thin.sch]
2023-01-05 Using new VREG, adds documentation for new VREG
    [XBee_Explorer Thin.brd, XBee_Explorer Thin.sch]
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2023-01-06 General placement of parts within the board
    [XBee_Explorer Thin.brd, XBee_Explorer Thin.sch]
2023-01-06 Even better locations for the parts
    [XBee_Explorer Thin.brd]
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2023-01-09 Routes more air wires
    [XBee_Explorer Thin.brd]
2023-01-09 Finishes routing air wires - optimizations next
    [XBee_Explorer Thin.brd]
2023-01-09 Removes VIN from pin one one header and puts it at pin 10
    * Shifts all other nets up one to accommodate VIN
    [XBee_Explorer Thin.brd, XBee_Explorer Thin.sch]
2023-01-09 Updates some of the routing
    [XBee_Explorer Thin.brd]
2023-01-09 Adds additional vias for 3.3V output
    [XBee_Explorer Thin.brd]
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2023-01-10 Improves the ground pour significantly
    [XBee_Explorer Thin.brd]
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2023-01-13 Fixes various DRC issues
    [XBee_Explorer Thin.brd]
2023-01-16 Fixes various schematic issues
    [XBee_Explorer Thin.brd, XBee_Explorer Thin.sch]
2023-01-16 Adds two layers and many stitching vias
    [XBee_Explorer Thin.brd]
2023-01-16 Adds many vias, rearranges some part placement for better performance/routing
    [XBee_Explorer Thin.brd]
2023-01-17 Adds more direct feeback trace for feedback pin on regulator
    * Restricts ground pour underneath the inductor (which still needs to be changed)
    * Updates USB lines to get closer to a 90 ohm impedance (8 mil, 6mil spacing)
    * Removes voltage divider on EN pin that was changing the UVLO threshold.
    [XBee_Explorer Thin.brd, XBee_Explorer Thin.sch]
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2023-01-17 Adds "UART" silk for other USB connector
    [XBee_Explorer Thin.brd]
2023-01-17 Updates footprint to include module outline, increases size of board, moves buttons
    [XBee_Explorer Thin.brd, XBee_Explorer Thin.sch]
2023-01-17 Moves some silk labels, approves some DRC
    [XBee_Explorer Thin.brd]
2023-01-17 Adds a few more stitching vias
    [XBee_Explorer Thin.brd]
2023-01-17 Runs the correct DRC with four layers
    [XBee_Explorer Thin.brd]
2023-01-17 Fixes mounting holes being off grid
    [XBee_Explorer Thin.brd]
2023-01-17 Replaces the only 0402 on the board with an 0603, replaces only 100k resistor with a 10k, fixes input/ouput labeling
    [XBee_Explorer Thin.brd, XBee_Explorer Thin.sch]
2023-01-17 Fixes DRC issue
    [XBee_Explorer Thin.brd]
2023-01-18 Moves resistor colliding with switch, adds via under UART to serial IC, adds "1,2,3,4" in their respective layer
    * Moves design to origin
    [XBee_Explorer Thin.brd, XBee_Explorer Thin.sch]
2023-01-18 Adds text for LED jumpers
    [XBee_Explorer Thin.sch]
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2023-01-18 Renames all files once again to include the "3" for XBee
    [SparkFun_XBee3_Cat1_Smart_Modem.brd, SparkFun_XBee3_Cat1_Smart_Modem.sch]
2023-01-19 Updates xbee sybmol to include pin numbers
    [SparkFun_XBee3_Cat1_Smart_Modem.brd, SparkFun_XBee3_Cat1_Smart_Modem.sch]
2023-01-27 Updates library to include a version of the module with silk
    * Replaces module in design with the silk-ed version
    * Extends board to be able to include the module's outline in silk
    * Moves buttons and through holes to fit new size
    * Changes name of the product to "Xbee 3 Dev Kit"
    * Moves switch to make space for new silk
    * Adds RSSI LED
    * Rolls version to v02
    [SparkFun_XBee3_Cat1_Smart_Modem.brd, SparkFun_XBee3_Cat1_Smart_Modem.sch]
2023-01-27 Adds silk to new LED and its' jumper
    [SparkFun_XBee3_Cat1_Smart_Modem.brd]
2023-01-27 NEW PINOUT - rearranges pinout to match module pinout directly
    [SparkFun_XBee3_Cat1_Smart_Modem.brd, SparkFun_XBee3_Cat1_Smart_Modem.sch]
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2023-01-27 Updates a few labels
    [SparkFun_XBee3_Cat1_Smart_Modem.brd]
2023-02-02 Replaces USB-C connector with four layer footprint
    [SparkFun_XBee3_Cat1_Smart_Modem.brd, SparkFun_XBee3_Cat1_Smart_Modem.sch]
2023-02-03 Updates title for USB-C section
    [SparkFun_XBee3_Cat1_Smart_Modem.sch]
2023-02-15 Fixes silk on modem and silk for certain through holes
    * Moves "VIN" and "EN" through holes
    * Moves the switch down because the above through holes moved
    * Shift the copper down to accommodate smaller XBee modules
    * Changes name to "Development Board"
    [SparkFun_XBee3_Cat1_Smart_Modem.brd, SparkFun_XBee3_Cat1_Smart_Modem.sch]
2023-02-15 Moves resistor for LEDs so that they're grouped in a better configuration
    [SparkFun_XBee3_Cat1_Smart_Modem.brd, SparkFun_XBee3_Cat1_Smart_Modem.sch]
2023-02-16 Fixes silk, aligns some text in the schematic, adds ordering instructions
    [SparkFun_XBee3_Cat1_Smart_Modem.brd, SparkFun_XBee3_Cat1_Smart_Modem.sch]
2023-02-17 Fixes a number of labels
    [SparkFun_XBee3_Cat1_Smart_Modem.brd]
2023-02-17 Updates single PTH with new footprint
    [SparkFun_XBee3_Cat1_Smart_Modem.brd, SparkFun_XBee3_Cat1_Smart_Modem.sch]
2023-02-24 Updates design to use the FT231XS instead of the CP2102N
    [SparkFun_XBee3_Cat1_Smart_Modem.brd, SparkFun_XBee3_Cat1_Smart_Modem.sch]
2023-02-24 Adds new 3.9uH Inductor
    [SparkFun_XBee3_Cat1_Smart_Modem.brd, SparkFun_XBee3_Cat1_Smart_Modem.sch]
2023-02-24 Fixes swapped labels on LED jumpers
    [SparkFun_XBee3_Cat1_Smart_Modem.brd]
2023-02-24 Fixes silk width on inductor, shifts part to correct keepout errors
    [SparkFun_XBee3_Cat1_Smart_Modem.brd, SparkFun_XBee3_Cat1_Smart_Modem.sch]
2023-02-24 Adds a few more vias
    [SparkFun_XBee3_Cat1_Smart_Modem.brd]
2023-02-27 Updates inductor to one with a higher saturation rating
    [SparkFun_XBee3_Cat1_Smart_Modem.brd, SparkFun_XBee3_Cat1_Smart_Modem.sch]
2023-02-27 Updates size of the silk on inductor, decreases dimension line
    [SparkFun_XBee3_Cat1_Smart_Modem.brd, SparkFun_XBee3_Cat1_Smart_Modem.sch]
2023-02-27 Adds production files, shifts buttons down just a bit
    [SparkFun_XBee_Development_Board-Panel.GBL, SparkFun_XBee_Development_Board-Panel.GBO, SparkFun_XBee_Development_Board-Panel.GBP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]
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2023-03-01 Updates XBee section with correct name
    [SparkFun_XBee_Development_Board.sch]
2023-04-13 Adds LED and Charging circuit - all routed (but not optimized
    [SparkFun_XBee_Development_Board.brd, SparkFun_XBee_Development_Board.sch]
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2023-04-14 Rolls version to v11 (applies to last commit)
    * Adds silk
    [SparkFun_XBee_Development_Board.brd, SparkFun_XBee_Development_Board.sch]
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2023-04-17 Swaps yellow user LED for a green one
    * Improves copper pour
    * Fixes some whacky traces
    [SparkFun_XBee_Development_Board.brd, SparkFun_XBee_Development_Board.sch]
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2023-04-17 Fixes the order of the capacitors
    [SparkFun_XBee_Development_Board.brd]
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2023-10-06 Moves ground pin nets to the bottom of the decoupling cap
    [SparkFun_XBee_Development_Board.brd, SparkFun_XBee_Development_Board.sch]
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2024-03-22 Adds text for USB calculation, nudges some things around for better pour
    [SparkFun_Digi_XBee_Development_Board.brd, SparkFun_Digi_XBee_Development_Board.sch]
2024-03-22 Moves from 100 OHm to 0 OHm on VCC input for FUSB42
    [SparkFun_Digi_XBee_Development_Board.brd, SparkFun_Digi_XBee_Development_Board.sch]
2024-03-22 Adds new panel - under new name unfortunately
    [SparkFun_Digi_XBee_Development_Board-Panel.GBL, SparkFun_Digi_XBee_Development_Board-Panel.GBO, SparkFun_Digi_XBee_Development_Board-Panel.GBP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]
2024-03-22 Adds version number to Production zip file, adds more notes to ordering instructions
    [SparkFun_Digi_XBee_Development_Board.brd]
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

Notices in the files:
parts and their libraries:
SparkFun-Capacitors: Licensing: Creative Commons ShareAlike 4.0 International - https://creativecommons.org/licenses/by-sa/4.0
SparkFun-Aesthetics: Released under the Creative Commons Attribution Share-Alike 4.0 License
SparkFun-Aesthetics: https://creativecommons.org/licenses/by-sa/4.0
